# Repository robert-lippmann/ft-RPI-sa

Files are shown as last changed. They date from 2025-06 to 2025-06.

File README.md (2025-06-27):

# ft-RPI-sa
The ft-RPI-sa controller is a versatile enhancement, developed to control models primarily built with fischertechnik but can be also used with Lego or any other kind of technical toy, limited to 12V supply and I/O voltage.
It consists of the main compute board (aka mainboard), covering all the required logic circuitry, and an additional I/O board with all the inputs and outputs to connect to the model. The I/O board features standard mini-banana-plug connectors with a diameter of 2.5mm. The mainboard can  optionally be used as a Raspberry Pi HAT and is supplied by either a battery set or an external 9V power supply.

# Mainboard V2.1 Top View
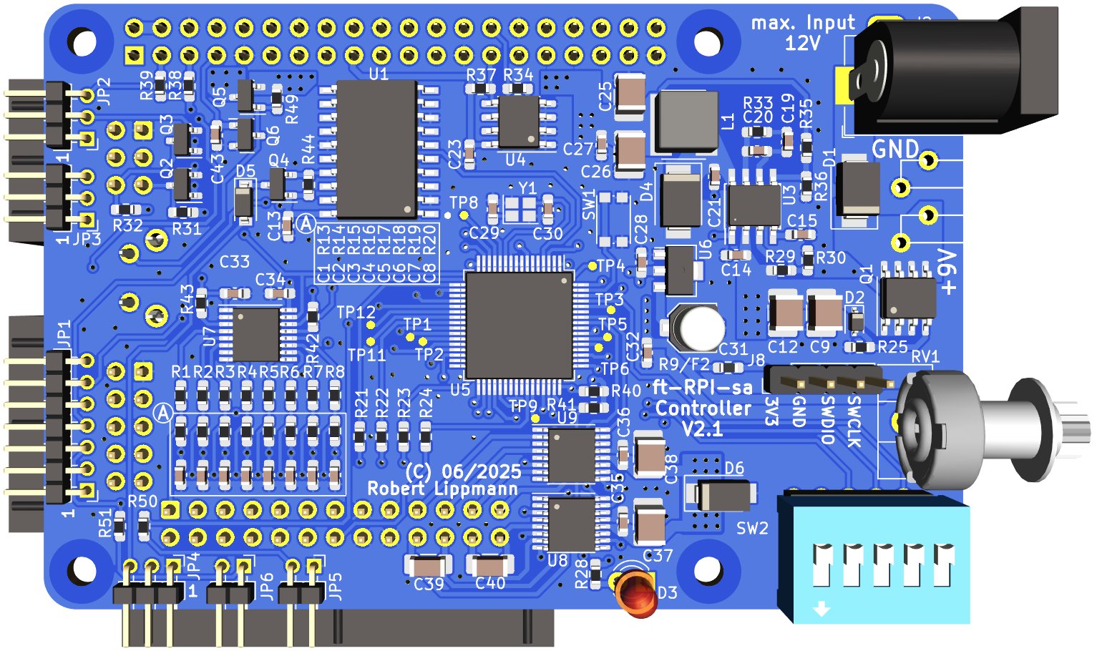
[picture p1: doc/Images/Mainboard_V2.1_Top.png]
Mainboard V2.1 Top view


# Mainboard V2.1 Bottom View
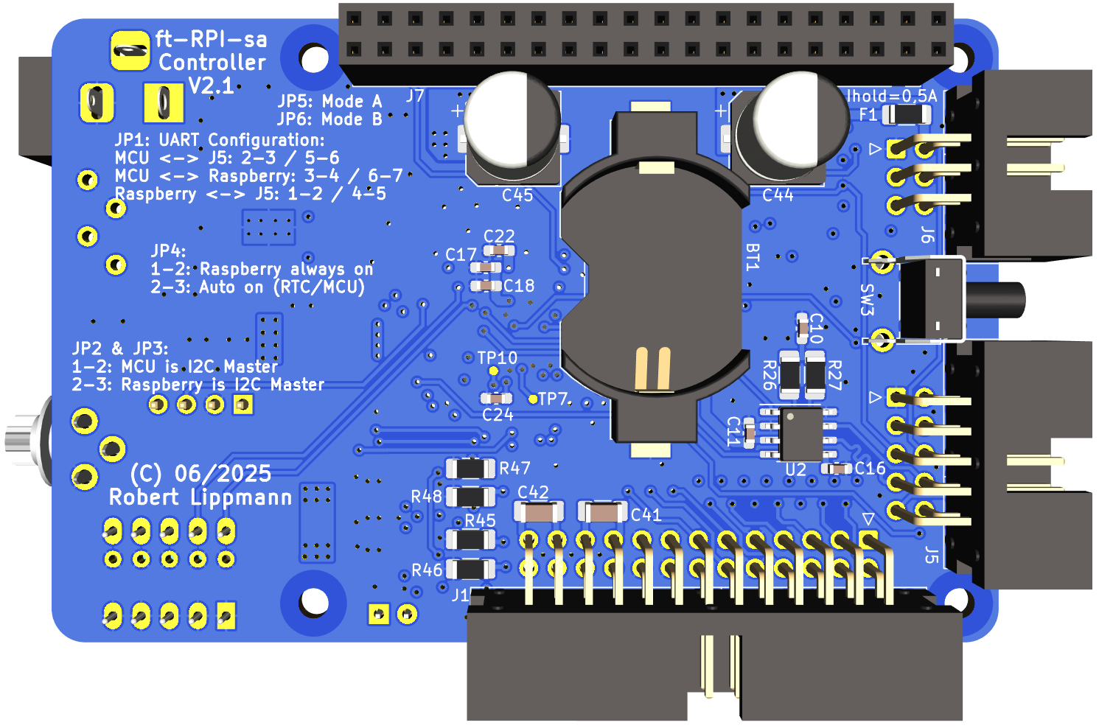
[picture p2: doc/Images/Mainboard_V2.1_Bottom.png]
Mainboard V2.1 Bottom view


# I/O Board Top View
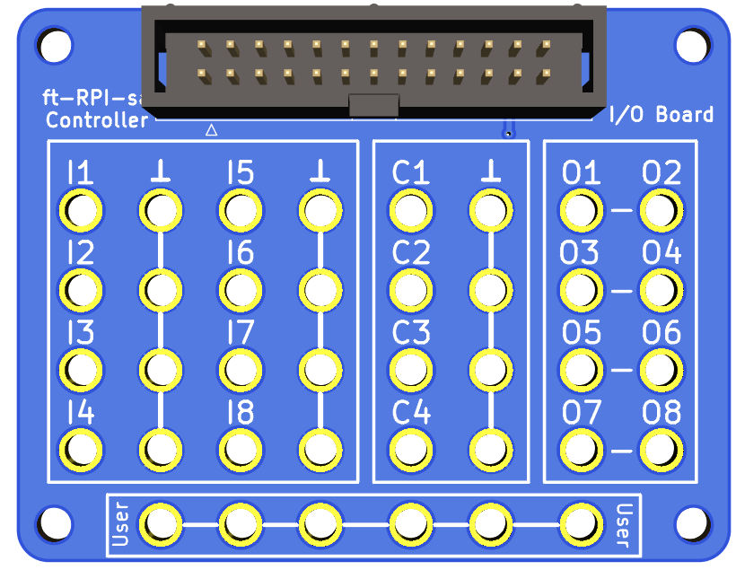
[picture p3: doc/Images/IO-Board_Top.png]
I/O Board Top view


# Features
 - Using NXP Microcontroller S32K142 or S32K144(W) or S32K146 w/o hardware modification
 - 8 independent 9V inputs (supporting analog & digital input capability with individual
   programable pull configuration)
 - 8 outputs which can be used independently or in combination for brushed or stepper Microcontroller
 - 4 independent 9V counter inputs which can use DMA for counting
 - Using a separate board for I/O connectors
 - Can be used as Raspberry Pi HAT with integrated power supply for the Raspberry Pi
 - Interfaces like UART (TTL), I2C (5V and 3V3), CAN-PHY, SPI (also useable with Raspberry Pi SPI1)
   to be used with additional peripherals
 - RTC incl. 512 Bytes RAM, w/ battery backup, useable for optional timed wakeup/activities
 - Full featured MMBasic interpreter including an editor running on S32K14x using UART
 - MMBasic interpreter enhanced with commands and functions to support on-board peripherals
 - Using a simple terminal program, running either on Raspberry Pi or on a PC/MAC, for SW development
 - Program transfer done via XMODEM up-/download to/from host computer
 - MMBasic program stored in D-Flash memory (64k) of MCU
 - Optional auto start of MMBasic application once powering up
 
# YouTube video
&nbsp;&nbsp;&nbsp;&nbsp;YouTube logo
 - [Video of 2 fischertechnik models controlled by the ft-RPI-sa](https://www.youtube.com/watch?v=sPbV3bQHXdk)

# Copyright and Acknowledgements

MMBasic interpreter:

Thanks to Geoff for granting me the permission to adapt his beautiful MMBasic interpreter to this hardware project and go public with it.
 - https://geoffg.net/micromite.html
 - Copyright 2011-2024 Geoff Graham
 - Copyright 2016-2024 Peter Mather

MMBasic enhancements and modifications related to ft-RPI-sa hardware:
- Copyright 2022-2025 Robert Lippmann
  
ft-RPI-sa Hardware:

- Copyright 2022-2025 Robert Lippmann

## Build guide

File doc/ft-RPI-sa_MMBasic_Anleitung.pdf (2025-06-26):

# ft-RPI-sa Controller

# (fischertechnik-Raspberry PI-stand-alone Controller) Anleitung HW Version 2.x MMBasic Version 5.05.05

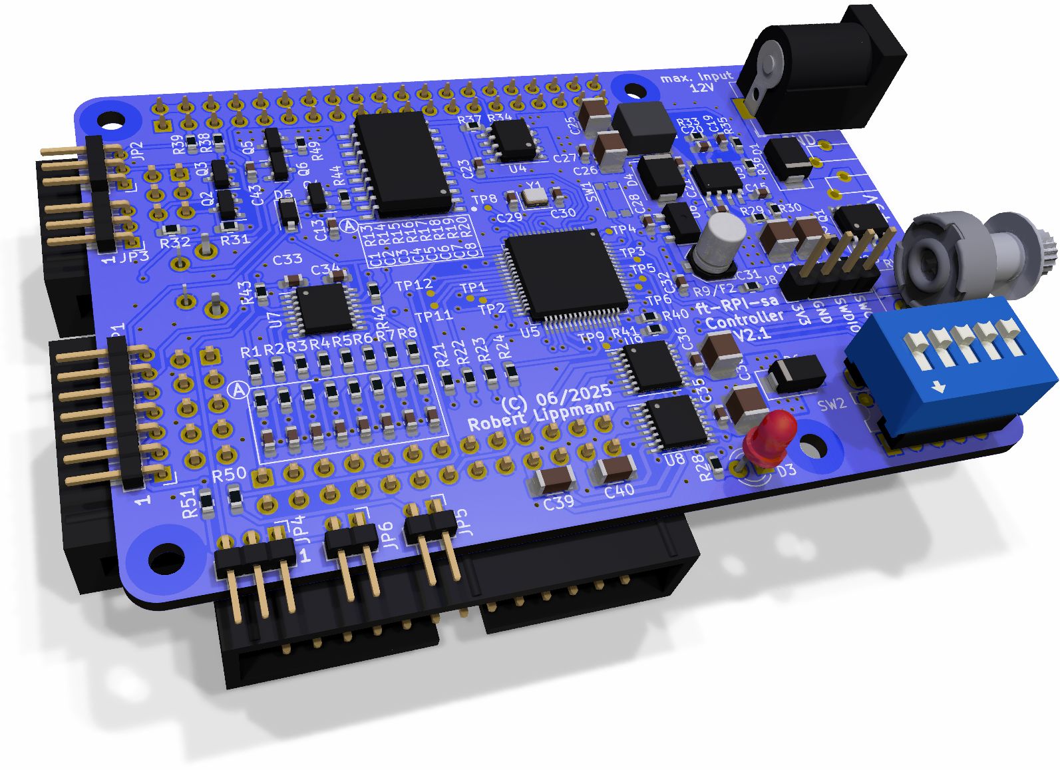
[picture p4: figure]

## MMBasic © Geoff Graham Hardware & S32K14x Adaptierung © Robert Lippmann Dokument V0.2 vom 21. Juni 2025 Projektkontakt: ft.mcu.prj@gmail.com

ft-RPI-sa Controller | Seite 1
Anleitung Version V0.2 | Entwurf

# Einleitung

Der ft-RPI-sa Controller ist ein kleiner Computer mit dem fischertechnik, Lego oder andere Technikmodelle, die mit 9V versorgt werden, gesteuert werden.
Der Controller besteht aus der Hauptplatine (auch Mainboard genannt), die all die benötigten Bausteine für die Steuerung beinhaltet, sowie einer zusätzlichem Ein-/Ausgabe Platine (I/O-Board) mit allen Anschlüssen für das zu steuernde Modell.
Die Hauptplatine, die optional auch als Raspberry Pi HAT verwendet werden kann, wird entweder durch ein passendes Batterie-Set oder Netzteil mit Spannung versorgt.

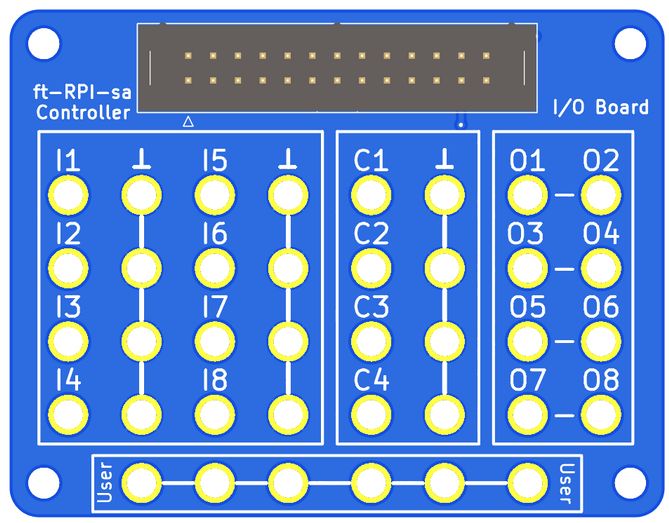
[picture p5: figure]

Das I/O Board

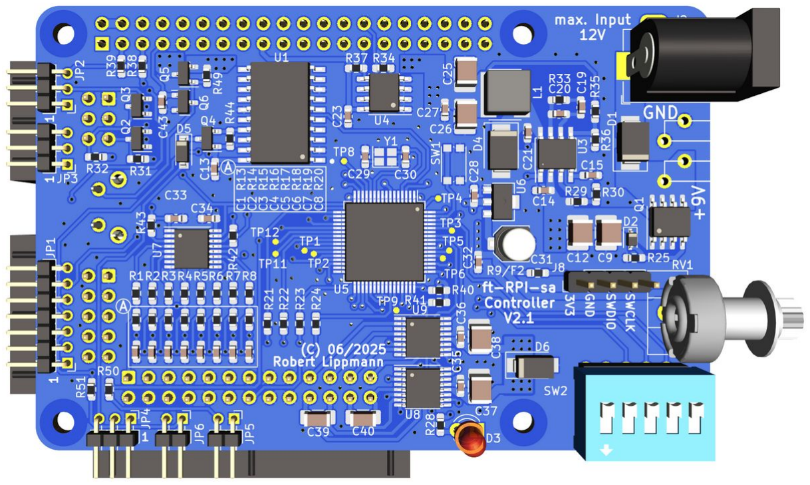
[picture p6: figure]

Das Mainboard

Das Mainboard beinhaltet einen Mikrocontroller (MCU), eine Echtzeituhr (RTC) mit Backup Batterie, Spannungsreglern, Ausgangstreibern (H-Brücken) und viele Anschlüsse sowie Konfigurationsbrücken.
Die benutzte MCU ist ein S32K144 Mikrocontroller der Firma NXP, die einen 32bit ARM CPU Kern des Typs M4F beinhaltet, welcher mit 80MHz betrieben wird. Neben der CPU besitzt die MCU viele weitere Peripheriemodule wie Flash Speicher (Programmspeicher), RAM Speicher (Arbeitsspeicher), UART, I2C, SPI, CAN, ADC, Timer etc.
Statt einer S32K144 MCU ist es auch möglich, einen anderen Typ der S32K1 Familie, im 64pin LQFP Gehäuse, zu verwenden (z.B. S32K118, S32K142(W) oder S32K146). Die Unterschiede der einzelnen MCUs, die die Leistung oder Fähigkeiten, des ft-RPI-sa Controllers beeinflussen, sind nachfolgend dargestellt:
MCU Typ | Flash Speicher | RAM Speicher | Max. CPU Geschwindigkeit | CPU Kern
S32K118¹ | 256kB | 25kB | 48MHz | Cortex M0+
S32K142(W) | | 32kB | 112MHz(80MHz) | Cortex M4
| 512kB | 64kB | incl. FPU S32K144(W)
S32K146 | 1024kB | 128kB | 112MHz
MCU Unterschiede

Wenn Du einen detaillierteren Überblick der K1 Familie haben willst, besuche die NXP Webseite. (https://www.nxp.com/products/processors-and-microcontrollers/s32-automotive-platform/s32k-auto-general-purpose-mcus/s32k1-microcontrollers-for-automotive-gene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) Dort gibt es auch das "Reference Manual", das jedes einzelne Bit der MCU erklärt.

1 Die MCU S32K118 hat keine FPU und somit sind die Fließkommaoperation deutlich langsamer, da diese in Software abgearbeitet werden müssen, und somit verweise ich auf diese MCU nur, da sie auf der Hardware eingesetzt werden kann, aber für MMBasic eignet sie sich nur bedingt.

ft-RPI-sa Controller | Seite 2

Das Mainboard kann entweder alleine, also Stand-Alone (sa), betrieben werden, oder es wird als sogenanntes HAT auf einen Raspberry Pi (RPI) gesteckt. Daher kommt auch die Bezeichnung RPI-sa Controller. Das ft am Anfang steht für fischertechnik, da ich den Controller hauptsächlich dafür entwickelt und getestet habe.

Programmiert wird der ft-RPI-sa mittels der Programmiersprache BASIC, welche schon sehr früh (ab 1964) in der Geschichte des Programmierens zu finden ist. BASIC ist sehr leicht zu erlernen und Erfolge beim Programmieren stellen sich sehr schnell ein. Das hier verwendete, so genannte MMBasic (Micromite BASIC), besitzt eine weitgehende Kompatibilität zu Microsofts GW-Basic. Dieses wurde nicht von mir, sondern von Geoff Graham entwickelt. Die Anpassung des BASIC Interpreters von Microchips PIC Familie an die NXP S32K1 Familie, sowie die Erweiterung um spezielle Instruktionen für den ft-RPI-sa, wurde von mir vorgenommen.

Wie kommt nun das BASIC Programm in den Controller? Dazu wird entweder ein Computer oder ein Raspberry PI benötigt. Sämtliche Kommunikation zwischen Controller und Computer geschieht über eine serielle Schnittstelle. Dafür sind 2 Leitungen, eine für das Senden und eine für das Empfangen der Daten, nötig. Die einfachste Art heutzutage diese beiden Leitungen mit einem PC zu verbinden, ist ein so genannter USB zu UART bzw. TTL Konverter. Dieser stellt auf dem Computer eine serielle Komponente, wie z.B. COM1 oder /dev/ttyUSB0 je nach verwendetem Betriebssystem, zur Verfügung, auf welche mit einem simplen Terminalprogramm, wie Putty, TeraTerm unter Windows oder minicom unter Linux, zugegriffen werden kann.

Eine andere, viel bequemere Möglichkeit um eine Verbindung herzustellen, ist die Verwendung eines Raspberry Pis. Dazu wird der ft-RPI-sa einfach auf den RPI gesteckt (HAT) und nach einer korrekten Konfiguration der Schnittstelle steht auch schon die Verbindung. Kein zusätzliches Kabel oder Konverter ist dazu nötig.

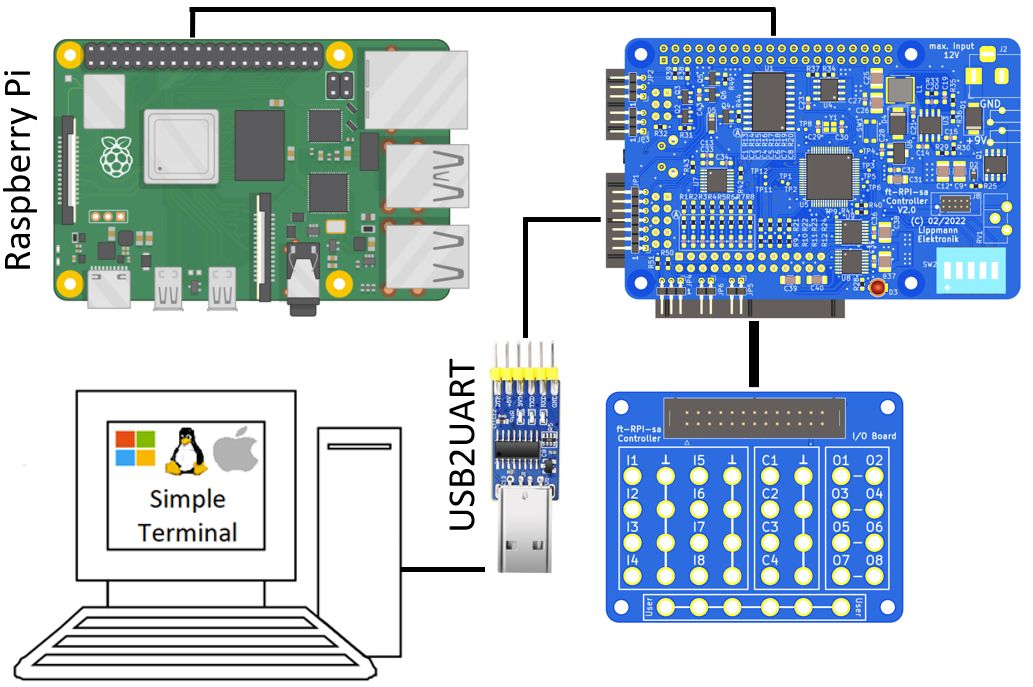
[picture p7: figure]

Verbindung über Computer oder Raspberry Pi

ft-RPI-sa Controller | Seite 3

# Die Hardware im Detail

Auf der Rückseite des Mainboards sind schon viele Konfigurationen festgehalten, aber längst nicht alle. Die folgenden Bilder sollen helfen, die Anschlüsse und deren Benutzung zu erklären:

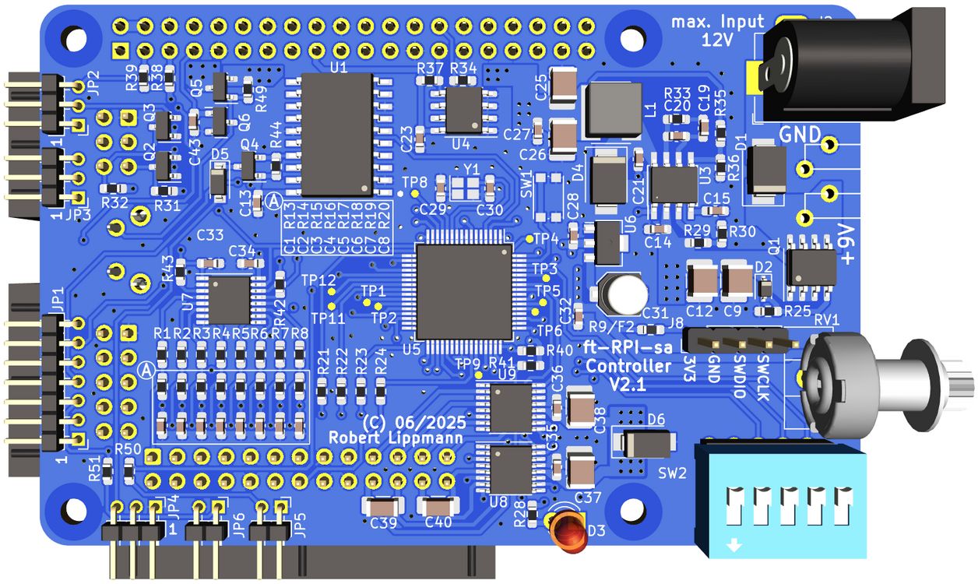
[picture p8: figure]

Ansicht Mainboard von oben

Beide Anschlüsse für die Stromversorgung sind gegen Verpolung geschützt!

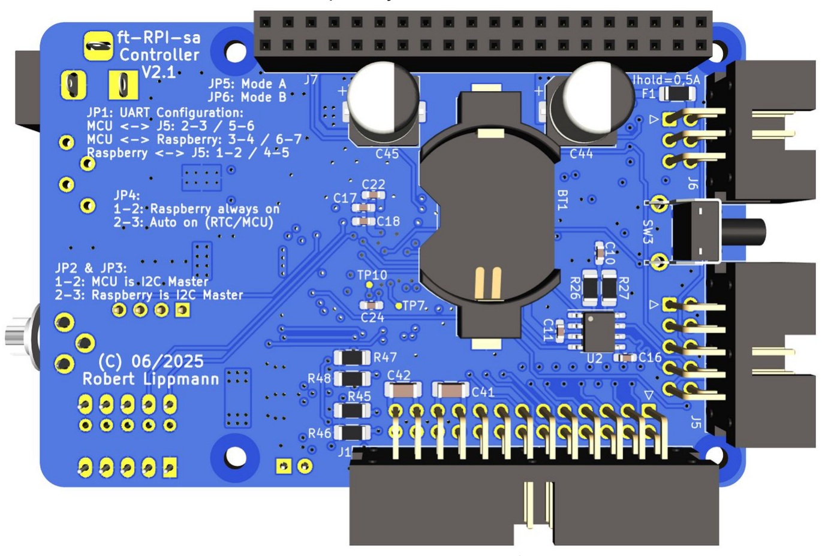
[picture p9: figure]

Ansicht Mainboard von unten

ft-RPI-sa Controller | Seite 4

J6:
I2C Schnittstelle (5V)
5V Stromversorgung für ext. Peripherie (max 0.5A /abgesichert) SW3:
Raspberry Pi Einschaltknopf

J5:
I2C Schnittstelle (3V3)
CAN Schnittstelle (5V)
UART (serielle Schnittstelle)

J7: Raspberry Pi Anschluss / SPI Schnittstelle

J2: Eingang
Stromversorgung (12V max)
GND (2.5mm Anschluss)
+9V (2.5mm Anschluss)

SW1: MCU RESET

J8: ARM Debugger Anschluss

Potentiometer

SW2: DIP Schalter

JP4: Raspberry Pi Versorgung Config D3: Versorgung/Status LED JP5/JP6: Für spezielle Modi

JP2/JP3: I2C Config

JP1: UART Config

J1: Anschluss für das I/O-Board

# Konfiguration

JP1
JP1: UART Konfiguration

Eine Verbindung zwischen:
2-3 & 5-6 : MCU ↔ J5 (Externer Computer mit Terminalprogramm) 3-4 & 6-7 : MCU ↔ Raspberry Pi (mit Terminalprogramm)
1-2 & 4-5 : Raspberry Pi ↔ J5

JP2 / JP3: I2C Konfiguration

1-2: MCU ist I2C Master (Standard für MMBasic Betrieb) | JP2
2-3: Raspberry Pi ist I2C Master

JP3

JP4 JP6 JP5
JP4: Raspberry Pi Versorgung
1-2: Raspberry PI ist immer an
2-3: Raspberry PI ist aus, kann aber über den Taster (SW3), die MCU oder einen RTC Alarm eingeschaltet werden
OFF: Raspberry Pi ist immer aus

JP5 / JP6:
Werden benötigt um den Bootloader zu aktivieren und eine neue Firmware einzuspielen.

J5 & J6: Anschlüsse für Peripherie

J6 | J5
5V I2C Anschluss | I2C/UART/CAN Anschluss
ft-RPI-sa Controller | Seite 5
SCL | SDA
NC | NC
+5V | GND
UART RX | UART TX
CANH | CANL
SCL | SDA
NC | NC
NC | GND

UART und I2C verwenden 3.3V CAN verwendet 5V

Die +5V können für externe Peripherie verwendet werden und sind mit 500mA abgesichert.

J7: Raspberry PI GPIO Anschluss
Dieser Anschluss ermöglicht ein aufstecken des Controllers auf den Raspberry PI (HAT = Hardware Attached to the Top).

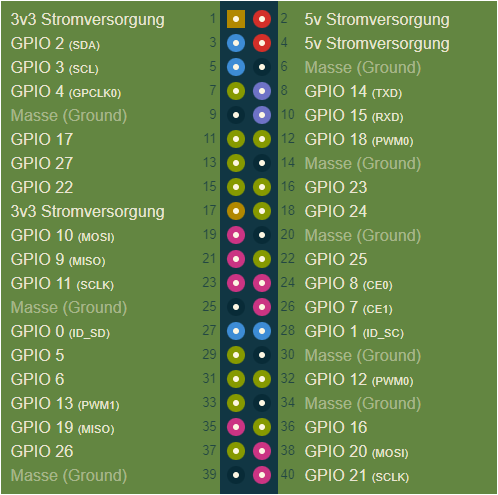
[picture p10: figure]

Raspberry Pi Belegung (https://de.pinout.xyz/)

Durch das Aufstecken des Controllers auf einen RPI wird die MCU interne LPSPI0 an die SPI1 des Raspberry Pis angeschlossen. Diese Art der synchronen, seriellen Schnittstelle ist verhältnismäßig schnell (bis zu 10MHz) und lässt sich relativ einfach verwenden.

SPI1 des RPIs an die LPSPI0 der MCU

Falls die Kommunikation, über die SPI1 des Raspberry Pis, zu dem ft-RPI-sa nicht verwendet wird, oder generell auf einen Raspberry Pi verzichtet wird, kann die MCU interne LPSPI0 für jede andere Art von Peripherie genutzt werden.

Weitere HATs können problemlos auf den ft-RPI-sa Controller gesteckt werden. Dazu musst Du nur darauf achten, dass GPIO4 nicht verwendet werden kann. Dieser wird dazu verwendet, dem ft-RPI-sa mitzuteilen, dass der Raspberry PI eingeschaltet ist und diesem die Versorgung nicht abschaltet ist.

Wie gerade erwähnt, wird der Raspberry Pi vom ft-RPI-sa Controller versorgt und stellt diesem auch einen Einschaltknopf bereit.
Abhängig von J4 kann der Raspberry PI sich aber auch automatisch einschalten, entweder per MCU oder per Alarm, gesteuert von der Echtzeituhr auf dem ft-RPI-sa.
Der Raspberry PI 4 verbraucht im Betrieb bei 5V ca. 600mA, kann aber auch bis zu 1.5A ansteigen, je nach Auslastung des Systems. Da ein sogenannter Schaltregler verwendet wird, um den Raspberry PI zu versorgen, beträgt der Strom auf der 9V Seite, je nach Auslastung, nur ca. 300mA bzw. ca. 800mA.
ft-RPI-sa Controller | Seite 6

Derzeit besteht die einzige Aufgabe des Raspberry PIs darin, den Standard PC als I/O Terminal zu ersetzten - weitere Einsatzmöglichkeiten sind aber schon geplant.

J1: I/O-Board Anschlüsse
Auf dieser Platine sind 2.5mm Buchsen untergebracht, von denen aus der Controller mit den einzelnen Sensoren und Aktoren der Modelle verbunden wird.

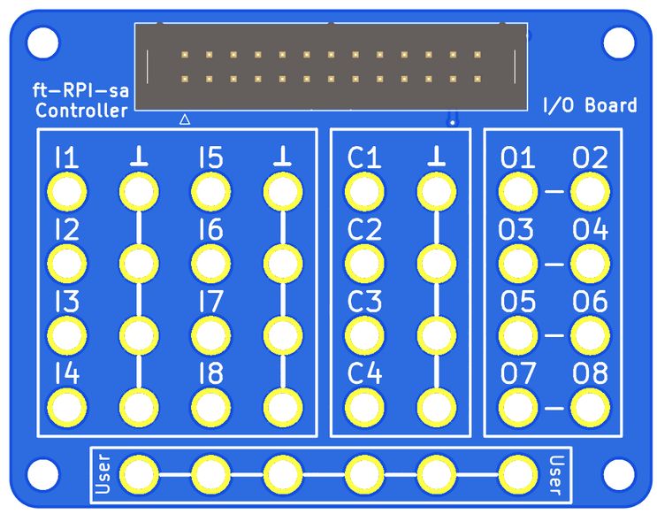
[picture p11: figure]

I/O Board

Alle GND (Masse) Verbindungen sind mit einem “Ʇ Symbol gekennzeichnet und miteinander verbunden.
Zusätzlich gibt es 8 Eingänge die mit I1 bis I8, sowie 4 Zählereingänge die mit C1 bis C4 gekennzeichnet sind. Neben all den Eingängen gibt es 8 Ausgänge O1 bis O8.
An der unteren Kante ist eine Reihe mit Buchsen versehen, die alle miteinander verbunden sind und die Kennzeichnung "User" haben. Diese 6 Buchsen können als Verteiler verwendet werden.

Die Ausgänge können verschiedenste Aktoren, wie (Schritt-)Motoren, Ventile, Elektromagnete, Lampen etc., mit maximal ~700mA steuern. Jeder der Ausgänge ist individuell steuerbar, für Motoren können jedoch 2 Ausgänge miteinander verbunden werden, um eine vollständige Kontrolle des Motors (Rechtslauf, Linkslauf, Schnelle Bremse oder Ausgleiten) zu bekommen. Dafür sind die zusammengehörigen Ausgänge mit einem Strich dazwischen, auf dem I/O Board gekennzeichnet.
Es kann auch ein Schrittmotor angeschlossen werden. Dazu sind jedoch 4 Ausgänge nötig. In diesem Fall werden die Ausgänge 1 bis 4, sowie 5 bis 8 gruppiert.

Die Eingänge I1 bis I8 sind alle identisch aufgebaut. Jeder der Eingänge verfügt über einen konfigurierbaren 2.7kΩ Pull Widerstand, der wahlweise nach +5V, nach GND oder ganz abgeschaltet werden kann. Mit diesem Pull Widerstand kann ein Eingang, auch wenn er nicht beschaltet ist, auf einen definierten Wert gebracht werden.

Die Zählereingänge C1 bis C4 besitzen keine Pull Möglichkeit und werden von der MCU auf zwei verschiedene Arten realisiert. Zum Einen wird jeder der Zählereingänge jede Millisekunde abgefragt und sobald eine stabile Zustandsänderung von 9V auf 0V stattgefunden hat, der Zähler um 1 weiter gezählt. Somit lassen sich Zustandsänderungen bis maximal 125 mal in der Sekunde erfassen, da für die stabile Zustandsänderung 2x 4 Durchläufe bzw. 8ms benötigt werden. Diese Methode ist dafür geeignet, mechanische Schalter abzufragen, da diese bei der Betätigung mehrere Impulse liefern - das sogenannte Prellen.
Zum Anderen verfügt die MCU über die Möglichkeit, eine Zustandsänderung automatisch zu erfassen ohne Zutun der CPU. Dies erlaubt es, mehr als 100000 Zustandsänderungen pro Sekunde zu verarbeiten. Diese Version der Zähler ist für jede prell-freie Quelle (z.B. Encoder-Motor) zu verwenden.
ft-RPI-sa Controller | Seite 7

# Der MMBasic Interpreter

Wie bereits erwähnt, ist MMBasic an das von Microsoft entwickelte GW-Basic angelehnt, jedoch verwendet es keine Zeilennummern. Dies ist ein wesentlicher Vorteil, da es somit nicht so leicht zu dem, bei BASIC Programmen besonders gefürchteten, Spaghetti-Code kommen kann.

# Das Terminal (oder: Die Konsole)

Um den ft-RPI-sa in MMBasic zu programmieren, benutzt man ein Terminal. Ein Terminal ist ein Programm auf dem PC, dass über eine serielle Schnittstelle eine Verbindung zum ft-RPI-sa Controller herstellt. Darüber kann man Kommandos eingeben, um den Controller zu konfigurieren oder zu programmieren, um ein BASIC Programm zu laden oder auch nur das BASIC Programm zu starten.
Das Terminal ist die einzige Möglichkeit um mit dem ft-RPI-sa Controller zu kommunizieren. Es ist daher essentiell diese Verbindung herzustellen. Eine serielle Verbindung besteht aus zwei Leitungen. Eine, oft bezeichnet als Tx, wird zum Senden der Daten und eine weitere Leitung, bezeichet als Rx, wird zum Empfangen der Daten verwendet. Die Nutzdaten, im ASCII Format, werden umrahmt von einem Start- und einem Stopbit:

Die Geschwindigkeit der Übertragung wird in Baud angegeben, was Bits pro Sekunde entspricht. Der ft-RPI-sa Controller verwendet, sobald er eingeschaltet wird, eine Geschwindigkeit von 19200 Baud. Diese kann jedoch, an das verwendete System, angepasst werden. Dazu später mehr. Der Signalpegel auf den Rx/Tx Leitungen schwankt, je nach zu
übertragendem Bit-Wert, zwischen 0V und 3.3V, auch TTL Pegel
genannt. Um diese beiden Leitungen nun an den PC anzuschließen,
ist ein Adapter von USB nach TTL nötig. Dieser ist bereits für kleines Geld im Internet erhältlich.
Dieser USB nach TTL Konverter stellt, sobald dieser am USB Port

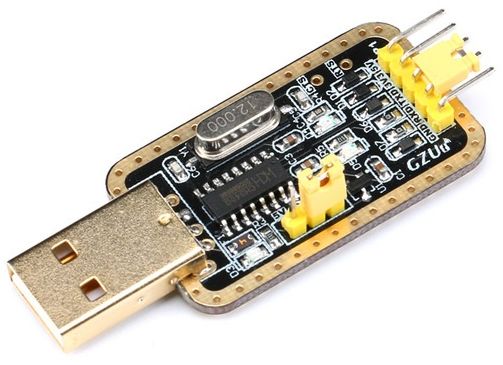
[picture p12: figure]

des Computer eingesteckt wird, ein serielles Interface zur Verfügung.
Je nach verwendetem Betriebssystem ist dies entweder "COMx"
(Windows) oder "/dev/ttyUSBx" (Linux). Das x entspricht einer Zahl
beginnend bei 1 (Win) oder 0 (Linux) und kann je nach Anzahl der verwendeten Adapter variieren. Auf diese Schnittstellen lässt sich nun mit Hilfe eines entsprechendem Terminalprogramms zugreifen. Unter Windows wäre dies z.B. Putty, TeraTerm und unter Linux kann z.B. minicom verwendet werden.
Um den ft-RPI-sa Controller nun mit dem PC zu verbinden, werden die entsprechenden Signale an dem Anschluss J5 abgegriffen und mit den Anschlüssen des Konverters verbunden:
J5/UART_RX -> USB2TTL TX sowie
J5/UART_TX -> USB2TTL RX
Jetzt kann jemand fragen, wieso nicht RX auf RX bzw. TX auf TX. Ganz einfach: Einen Sender (TX) muss man an einen Empfänger (RX) anschließen.
Eine weitere, bis jetzt noch nicht erwähnte Leitung, muss ebenfalls angeschlossen werden: GND Dies ist der gemeinsame Bezugspunkt zwischen Computer und ft-RPI-sa Controller.
Sobald alle drei Leitungen verdrahtet sind, kann die erste Kontaktaufnahme gestartet werden und im richtig konfiguriertem Terminalprogramm sollte nach dem Einschalten des ft-RPI-sa Controllers ungefähr folgendes zu sehen sein:
ft-RPI-sa Controller | Seite 8

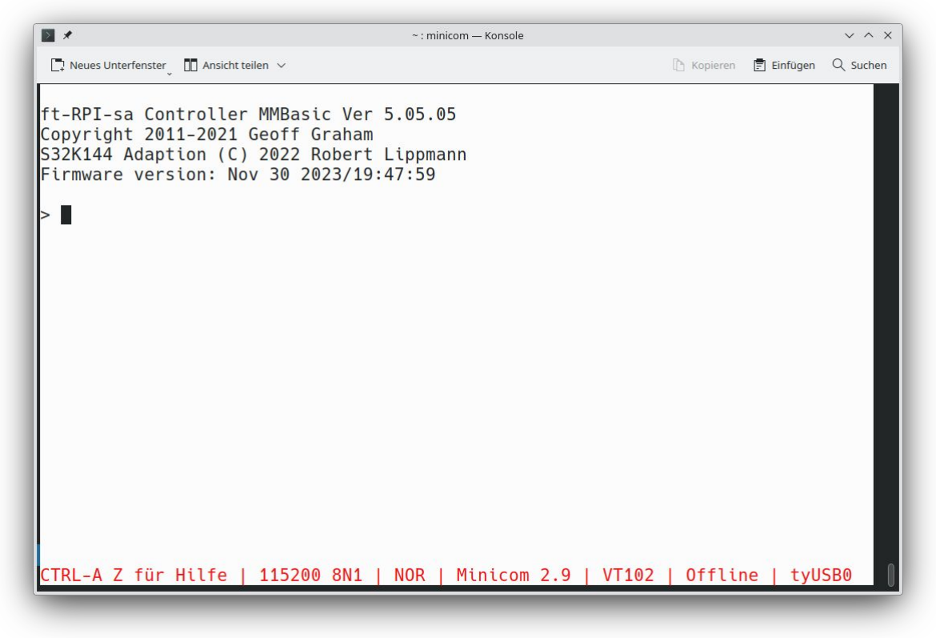
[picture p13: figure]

Falls dies nicht der Fall sein sollte: KEINE PANIK!
- Leuchtet die Status-/Power-LED des ft-RPI-sa?
- Sind die beiden Kurzschlussbrücken an JP1 richtig gesetzt?
- Stimmt die eingestellte Baudrate, also Übertragungsgeschwindigkeit, überein?
- Stimmen die Übertragungsparameter (8 Datenbits, 1 Stopbit und keine Parität)?
- Sind die Verbindungen von ft-RPI-sa zu USB2TTL korrekt?
- Funktioniert der USB2TTL Konverter? (Test: Kurzschlussbrücke am USB2TTL auf RX/TX setzen und tippen - jedes gesendetes Zeichen sollte im Terminalprogramm zu sehen sein)

Falls ein Raspberry Pi griffbereit ist, kann der ft-RPI-sa Controller auch auf den Raspberry Pi gesteckt werden. In diesem Fall ist kein USB2TTL Converter nötig und nach entsprechendem konfigurieren der Kurzschlussbrücken auf JP1 kann der Raspberry Pi auch schon den PC ersetzen.

Da MMBasic selbst, sowie dessen Befehls- und Funktionsumfang, vom Autor Geoff Graham bereits ordentlich dokumentiert wurde, folgt hier nun eine Kopie seines erstellten Dokuments mit Anpassungen bezüglich ft-RPI-sa spezifischen Befehlen und Funktionen:

ft-RPI-sa Controller | Seite 9

# Interacting with MMBasic

The ft-RPI-sa is rather like a self contained computer. You can write programs, run them, edit them and so on, all on the ft-RPI-sa itself. And if your program has an error (as initially
all do) you will get a clear message showing you where the fault is located and what the
problem is. This is different from other systems where you build your program on a
separate computer then download the compiled result to the chip to be run. In that case you do not get any feedback on errors while your program is running… it will just produce crazy results and you will have no idea where or what in your program caused the problem.
This is an important part of working with the ft-RPI-sa – it is much easier and quicker to build a functioning program when you can get immediate feedback and then, with one keystroke, jump into an editor to fix the issue and run the program again.
This interaction with the ft-RPI-sa is done via the console at the command prompt (ie, the greater than symbol (>) on the console). On startup the ft-RPI-sa will issue the command prompt and wait for some command to be entered. It will also return to the command prompt if your program ends or if it generated an error message.
When the command prompt is displayed you have a wide range of commands that you can execute.
Typically your commands would list the program held in flash memory (LIST) or edit it (EDIT) or perhaps set some options (the OPTION command). Most times the command is just RUN which instructs MMBasic to run the program held in flash memory.
Almost any command can be entered at the command prompt and this is often used to test a command to see how it works. A simple example is the PRINT command (more on this in Chapter 3), which you can test by entering the following at the command prompt:

PRINT 2 + 2
and not surprisingly MMBasic will print out the number 4 before returning to the command prompt. This ability to test a command at the command prompt is very useful when you are learning to program in BASIC, so it would be worthwhile having a ft-RPI-sa handy for the occasional test while you are working through this tutorial.

# Break Key

One useful feature of the ft-RPI-sa is the CTRL-C sequence (hold down the CTRL key then press the C key). This is called the break key or character. When you type this on the console’s input it will interrupt whatever the ft-RPI-sa is doing and immediately return control to the command prompt.
This can get you out of all sorts of difficult situations. For example, if you entered the following at the command prompt you would cause MMBasic to enter a continuous loop and appear to be unresponsive.
DO : LOOP
If you have a ft-RPI-sa handy you can try entering this line and you will see that the command prompt does not return because MMBasic is busy spinning in a loop. Then try typing CTRL-C on the console and the ft-RPI-sa will immediately break out of the loop and return to the command prompt.
Remember CTRL-C because it will prove useful at some time in the future.
ft-RPI-sa Controller | Seite 10

The Editor
The ft-RPI-sa has its own built in program editor which can be used to enter programs and correct them when errors are discovered. This screen shot shows the editor in action with colour coded text. Commands are in cyan, comments in yellow, constants in green and so on as shown below.

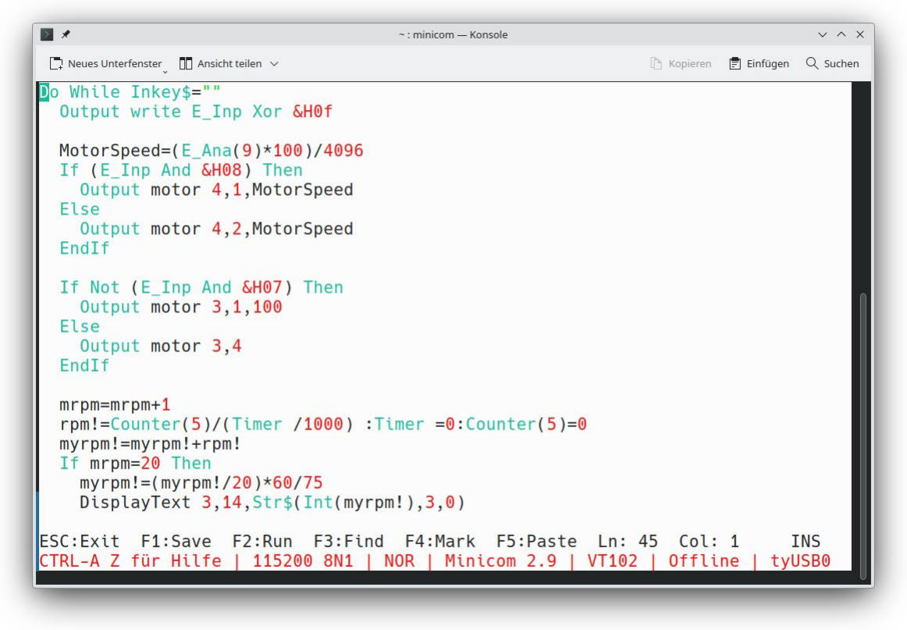
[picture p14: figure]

The best way to understand the editor is to try it out. At the command prompt enter the command EDIT and the editor will startup displaying an empty screen with a help line at the bottom of the screen. You can then just type in your program. For example, try typing in:
PRINT 1/7
Then press the F2 key on your keyboard. This will save the program to memory and run it. This will display the result of dividing 1 by 7.
To change this program use the command EDIT again and you will be taken back into the editor with your program displayed ready for editing.
If you have used an editor like Windows Notepad in the past you will find the operation of this editor familiar. The arrow keys will move your cursor around in the text while the home and end keys will take you to the beginning or end of the line. Page up and page down will do what their titles suggest. The delete key will delete the character at the cursor and backspace will delete the character before the cursor.

About the only unusual key combination is that two home key presses will take you to the start of the program and two end key presses will take you to the end. At the bottom of the screen the status
line will list the various function keys used by the editor and their action. In more details these are:
ft-RPI-sa Controller | Seite 11

ESC | This will cause the editor to abandon all changes and return to the command prompt with the program memory unchanged. If you have changed the text you will be asked if you really want to discard your changes.
F1: SAVE | This will save the program to program memory and return to the command prompt.
F2: RUN | This will save the program to program memory and immediately run it.
F3: FIND | This will prompt for the text that you want to search for. When you press enter the cursor will be placed at the start of the first entry found.
SHIFT-F3 | After you have used the search function once you can repeatedly search for the same text by pressing SHIFT-F3.
F4: MARK | This is described in detail below.
F5: PASTE | This will insert (at the current cursor position) the text that had been previously cut or copied to the ft-RPI-sa clipboard (see below).

If you pressed the mark key (F4) the editor will change to the mark mode. In this mode you can use the arrow keys to mark a section of text which will be highlighted in reverse video. You can then delete, cut or copy the marked text to the ft-RPI-sa's clipboard. In this mode the status line will change to show the functions of the function keys in the mark mode. These keys are:

ESC
F4: CUT
F5: COPY
DELETE

Will exit mark mode without changing anything.
Will copy the marked text to the clipboard and remove it from the text. Will just copy the marked text to the clipboard.
Will delete the text leaving the clipboard unchanged.
One point to note is that you cannot use the Windows/Linux Copy and Paste function to paste text into the terminal emulator and expect the editor to accept it. This is because the editor has a lot of work to do for each character received and it cannot keep up with a high speed transfer like that. If you do want to copy and paste a program into the terminal emulator you should use the
AUTOSAVE command described below.

# Loading a Program from a PC

If you prepare a program on your desktop computer you can transfer it to the ft-RPI-sa using either the AUTOSAVE or XMODEM commands. This requires you to have a terminal emulator running on your desktop machine and connected to the console of the ft-RPI-sa. How to do this was described in the previous chapter.
The AUTOSAVE command puts the ft-RPI-sa into a mode where anything received on the console will be saved to the program memory. This means that you can simply copy the text and paste it into the terminal emulator (eg, minicom) which will send it to the ft-RPI-sa. From the ft-RPI-sa’s perspective pasting text into the terminal emulator is the same as if a high speed typist was typing in the program. To terminate the AUTOSAVE command you need to press the Control-Z keys in the terminal emulator and the ft-RPI-sa will save the program to its memory and return to the command prompt.
You can try this if you have a ft-RPI-sa in front of you. At the console type AUTOSAVE and
press Enter. You will see nothing on the screen because the ft-RPI-sa is waiting for the input.
Copy the program to your computer's clipboard and paste it into your terminal emulator. You should see the program text being echoed back. Enter CTRL-Z and MMBasic will confirm that it has saved the program. Then it is just a case of entering RUN at the command prompt.
The XMODEM command is more sophisticated, it uses the XModem protocol to transfer a BASIC
ft-RPI-sa Controller | Seite 12

program file from your personal computer to the ft-RPI-sa including an integrity check which will detect any errors in the transfer. This program file will be saved in the ft-RPI-sa’s memory ready to be run.
To start the XModem transfer you need to tell the ft-RPI-sa to receive the file. The command to do this is:

XMODEM RECEIVE

This instructs the ft-RPI-sa to look for an XModem connection on the console. After running this command you should then instruct your terminal program to send the file using the XModem protocol. In minicom (running on your PC) this is done by using the following menu selection: CTRL-A → Z → S → XMODEM
This will present a dialog box where you can enter/select the name of the file to be sent and when you click on OK the transfer will start. When the complete file has been received the ft-RPI-sa will save it in program memory and return to the command prompt.

# Setting Options

There are many options that you can set in the ft-RPI-sa and these are all set using the OPTION command. These settings are divided into some that will only last for the duration of the currently running program and therefore are used in a program and others that will be remembered even after
the power has been removed. These are most often entered at the command prompt.
When the ft-RPI-sa is first used the options will have been set to reasonable defaults, so you should not need to change them. But, to give you the flavor of what you can do, the following is a summary of the important settings that are available.
OPTION AUTORUN OFF | ON
OPTION BASE [0 | 1]
OPTION BAUDRATE nbr
OPTION BREAK nn
OPTION CASE [UPPER | LOWER | TITLE]
OPTION COLOURCODE ON | OFF
OPTION DEFAULT [FLOAT | INTEGER | STRING |
NONE]
OPTION DISPLAY lines [,chars]
OPTION EXPLICIT

OPTION RESET
OPTION TAB [2 | 4 | 8]

Run the program when power is applied Set the lower limit of arrays
Change the baudrate of the console
Set the character that will break out of a program
Set the format for listing commands Enable colour coding in the program editor
Set the default type of a variable

Size of the display for listing programs Require that variables be properly declared
Reset all options to their defaults
Set the size of tabs
ft-RPI-sa Controller | Seite 13

# Programming Fundamentals

The ft-RPI-sa is programmed using the BASIC programming language. The ft-RPI-sa
version of BASIC is called MMBasic (short for the origin MicroMite BASIC) which is loosely based on the Microsoft BASIC interpreter that was popular years ago.
The BASIC language was introduced in 1964 by Dartmouth College in the USA as a computer language for teaching programming and accordingly it is easy to use and learn. At the same time, it has proved to be a competent and powerful programming language and as a result it became very popular in the 70s and 80s. Even today some large commercial data systems are still written in the BASIC language (primarily Pick Basic).
For the ft-RPI-sa the greatest advantage of BASIC is its ease of use. Some more modern languages such as C and C++ can be truly mind bending but with BASIC you can start with a one line program and get something sensible out of it. MMBasic is also powerful in that you can control the I/O pins on the ft-RPI-sa or communicate with other chips using a range of built-in communications protocols.
The only significant downside to using a BASIC interpreter is that it is not as fast as a fully compiled language like C or C++. However, on a fast microcontroller such as the S32K144W MMBasic will execute each command in an average of 50µs or faster. This speed is suitable for most applications - for example, it is fast enough to respond to a high revving engine and deal with signals such as ignition triggers.

# Structure of a BASIC Program

A BASIC program starts at the first line and continues until it runs off the end of the program or hits an END command - at which point MMBasic will display the command prompt (>) on the console and wait for something to be entered.
A program consists of a number of statements or commands, each of which will cause the BASIC interpreter to do something (the words statement and command generally mean the same and are used interchangeable in this book). Normally each statement is on its own line but you can have multiple statements in the one line separated by the colon character (:). For example;
A = 24.6 : PRINT A
Each line can start with a line number. Line numbers were mandatory in the early BASIC interpreters however modern implementations (such as MMBasic) do not need them. You can still use them if you wish but they have no benefit and generally just clutter up your programs. This is an example of a program that uses line numbers:

50 A = 24.6
60 PRINT A

A line can also start with a label which can be used as the target for a program jump using the GOTO command. This will be explained in more detail when we cover the GOTO command but this is an example (the label name is JmpBack):

JmpBack: A = A + 1
PRINT A
GOTO JmpBack

# The PRINT Command

There are a number of common commands that are fundamental and we will cover them in this

ft-RPI-sa Controller | Seite 14

chapter but arguably the most useful is the PRINT command. Its job is simple; to print something on the console. This is mostly used to tell you how your program is running and can consist of something simple such as "Pump running" or "Total Flow: 23 litres".
PRINT is also useful when you are tracing a fault in your program; you can use it to print out the values of variables, I/O pins and display messages at key stages in the execution of the program. In its simplest form the command will just print whatever is on its command line. So, for example:

PRINT 54

Will display on the console the number 54 followed by a new line.
The data to be printed can be an expression, which means something to be calculated. We will cover expressions in more detail later but as an example the following:

> PRINT 3/21
0.142857
>

would calculate the result of three divided by twenty one and display it. Note that the greater than symbol (>) is the command prompt produced by MMBasic – you do not type that in.
Other examples of the PRINT command include:

> PRINT "Hello World"
Hello World
> PRINT (999 + 1) / 5
200
>

You can try these out at the command prompt.
The PRINT command will also work with multiple values at the same time, for example:

> PRINT "The amount is" 345 " and the second amount is" 456
The amount is 345 and the second amount is 456
>

Normally each value is separated by a space character as shown in the previous example but you can also separate values with a comma (,). The comma will cause a tab to be inserted between the two values. In MMBasic tabs in the PRINT command are eight characters apart. To illustrate tabbing the following command prints a tabbed list of numbers:

> PRINT 12, 34, 9.4, 1000
12 34 9.4 1000
>

Note that there is a space printed before each number. This space is a place holder for the minus symbol (-) in case the value is negative. Notice the difference with the number 12 in this example:

> PRINT -12, 34, -9.4, 1000
-12 34 -9.4 1000
>

The print statement can be terminated with a semicolon (;). This will prevent the PRINT command from moving to a new line when it completes printing all the text. For example:

PRINT "This will be";

ft-RPI-sa Controller | Seite 15

PRINT " printed on a single line."

Will result in this output:

This will be printed on a single line.

The message would be look like this without the semicolon at the end of the first line:

This will be
printed on a single line.

# Variables

Before we go much further we need to define what a "variable" is as they are fundamental to the operation of the BASIC language (in fact, any programming language). A variable is simply a place to store an item of data (ie, its "value"). This value can be changed as the program runs which
why it is called a "variable".
Variables in MMBasic can be one of three types. The most common is floating point and this is automatically assumed if the type of the variable is not specified. The other two types are integer and string and we will cover them later. A floating point number is an ordinary number which can contain a decimal point. For example 3.45 or -0.023 or 100.00 are all floating point numbers.
A variable can be used to store a number and it can then be used in the same manner as the number
itself, in which case it will represent the value of the last number assigned to it.
As a simple example:

A = 3
B = 4
PRINT A + B

will display the number 7. In this case both A and B are variables and MMBasic used their current values in the PRINT statement. MMBasic will automatically create a variable when it first encounters it so the statement A = 3 both created a floating point variable (the default type) with the name of A and then it assigned the value of 3 to it.
The name of a variable must start with a letter while the remainder of the name can use letters, numbers, the underscore or the full stop (or period) characters. The name can be up to 32 characters
long and the case (ie, capitals or not) is not important. Here are some examples:

Total_Count
ForeColour
temp3
count

You can change the value of a variable anywhere in your program by using the assignment command, ie:

variable = expression

For example:

ft-RPI-sa Controller | Seite 16

temp3 = 24.6
count = 5
CTemp = (FTemp – 32) * 0.5556

In the last example both CTemp and FTemp are variables and this line converts the value of FTemp (in degrees Fahrenheit) to degrees Celsius and stores the result in the variable Ctemp.

# Expressions

We have met the term ‘expression’ before in this tutorial and in programming it has a specific meaning. It is a formula which can be resolved by the BASIC interpreter to a single number or value.
MMBasic will evaluate a mathematical expression using the same rules that we all learnt at school. For example, multiplication and division are performed first followed by addition and subtraction. These are called the rules of precedence and are fully spelt out in the manual (around page 52). This means that 2 + 3 * 6 will resolve to 20, so will 5 * 4 and also 10 + 4 * 3 – 2.
If you want to force the interpreter to evaluate parts of the expression first you can surround that part of the expression with brackets. For example, (10 + 4) * (3 – 2) will resolve to 14 not 20 as would have been the case if the brackets were not used. Using brackets does not appreciably slow down the program so you should use them liberally if there is a chance that MMBasic will misinterpret your expression.
As pointed out earlier, you can use variables in an expression exactly the same as straight numbers.
For example, this will increment the value of the variable temp by one:

temp = temp + 1

You can also use functions in expressions. These are special operations provided by MMBasic, for example to calculate trigonometric values. As an example, the following will print the length of the hypotenuse of a right angled triangle using the SQR() function which returns the square root of a number (a and b are variables holding the lengths of the other sides):

PRINT SQR(a * a + b * b)

MMBasic will first evaluate this expression by multiplying a by a, then multiplying b by b, then adding the results together. The resulting number is then passed to the SQR() function which will calculate the square root of that number and return it for the PRINT command to display.
Some other mathematical functions provided by MMBasic include:
SIN(r) – the sine of r
COS(r) – the cosine of r
TAN(r) – the tangent of r
There are many more functions available to you and they are all listed in the User Manual.
Note that in the above functions the value passed to the function (ie, 'r') is the angle in radians. In MMBasic you can use the function RAD(d) to convert an angle from degrees to radians ('d' is the angle in degrees).

Another feature of BASIC is that you can nest function calls within each other. For example, given the angle in degrees (ie, 'd') the sine of that angle can be found with this expression:

ft-RPI-sa Controller | Seite 17

PRINT SIN(RAD(d))

In this case MMBasic will first take the value of d and convert it to radians using the RAD() function. The output of this function then becomes the input to the SIN() function.

# The IF statement

Making decisions is at the core of most computer programs and in BASIC that is usually done with the IF statement. This is written almost like an English sentence:
IF condition THEN action
The condition is usually a comparison such as equals, less than, more than, etc. For example:
IF Temp < 25 THEN PRINT "Cold"
Temp would be a variable holding the current temperature (in ºC).
There are a range of tests that you can make:
=
<
>

equals
less than
greater than

<>
<=
>=

not equal
less than or equals
greater than or equals

You can also add an ELSE clause which will be executed if the initial condition tested false. For example, this will execute different actions when the temperature is under 25 or 25 or more:

IF Temp < 25 THEN PRINT "Cold" ELSE PRINT "Hot"

The previous examples all used single line IF statements but you can also have multiline IF statements. They look like this:

IF condition THEN
TrueActions
ENDIF

Or, if you also want to take some actions if false:

IF condition THEN
TrueActions
ELSE
FalseActions
ENDIF

Unlike the single line IF statement you can have many true actions with each on their own line and similarly many false actions. Generally the single line IF statement is handy if you have a simple action that needs to be taken while the multiline version is much easier to understand if the actions are numerous and more complicated.
An example of a multiline IF statement with more than one action is:

IF Temp < 25 THEN
PRINT "Cold"
TurnRedLightOff
ELSE
PRINT "Hot"
ft-RPI-sa Controller | Seite 18

TurnRedLightOn
ENDIF

Note that in the above example each action is indented to show what part of the IF structure it belongs to. Indenting is not mandatory but it makes a program much easier to understand for someone who is not familiar with it and therefore it is highly recommended. You will find that this tutorial uses indenting in all examples for this reason.
In a multiline IF statement you can make additional tests using the ELSE IF command. This is best explained by using an example:

IF Temp < 0 THEN
PRINT “Freezing”
ELSE IF Temp < 25 THEN
PRINT “Cold”
ELSE IF Temp < 40 THEN
PRINT “Warm”
ELSE
PRINT “Hot”
ENDIF

The ELSE IF can use the same tests as an ordinary IF (ie, <, <=, etc) but that test will only be made
if the preceding test was false. So, for example, you will only get the message Warm if Temp < 0 failed, and Temp < 25 failed but Temp < 40 was true. The final ELSE will catch the case
where all the tests were false.
An expression like Temp < 25 is evaluated by MMBasic as either true or false with true having a value of one and false zero. You can see this if you entered the following at the console:

PRINT 30 > 20

MMBasic will print 1 meaning that the value is true and similarly the following will print 0 meaning that the expression evaluated to false.

PRINT 30 < 20

The IF statement does not really care about what the condition actually is, it just evaluates the condition and if the result is zero it will take that as false and if non zero it will take it as true. This allows for some handy shortcuts. For example, if SwitchOn is a variable that is true (non zero) when some switch is turned on the following can be used to make a decision based on that value: IF SwitchOn THEN …do something…
FOR Loops
Another common requirement in programming is repeating a set of actions. For instance, you might want to step through all seven days in the week and perform the same function for each day. BASIC provides the FOR loop construct for this type of job and it works like this:

FOR day = 1 TO 7

Do something based on the value of ‘day’

NEXT day

This starts by creating the variable day and assigning the value of 1 to it. The program then will execute the following statements until it comes to the NEXT statement. This tells the BASIC

ft-RPI-sa Controller | Seite 19

interpreter to increment the value of day, go back to the previous FOR statement and re-execute the
following statements a second time. This will continue looping around until the value of day exceeds 7 and the program will then exit the loop and continue with the statements following the NEXT statement.

As a simple example, you can print the numbers from one to ten like this:
FOR nbr = 1 TO 10
PRINT nbr,;
NEXT nbr
The comma at the end of the PRINT statement tells the interpreter to tab to the next tab column after printing the number while the semicolon will leave the cursor on this line rather than automatically moving to the next line. As a result the numbers will be printed in neat columns across the page. Try it on a ft-RPI-sa, use the EDIT command to enter the short program listed above then press the F2 key to save and run it.
The FOR loop also has a couple of extra tricks up it sleeve. You can change the amount that the variable is incremented by using the STEP keyword. So, for example, the following will print just the odd numbers:

FOR nbr = 1 TO 10 STEP 2
PRINT nbr,;
NEXT nbr

The value of the step (or increment value) defaults to one if the STEP keyword is not used but you can set it to whatever number you want.
When MMBasic is incrementing the variable it checks to see if the variable has exceeded the TO value and, if it has, it will exit from the loop. So, in the above example, the value of nbr will reach nine and it will be printed but on the next loop nbr will be eleven and at that point execution will leave the loop. This test is also applied at the start of the loop (ie, if in the beginning the value of the variable exceeds the TO value the loop will never be executed, not even once).
By setting the STEP value to a negative number you can use the FOR loop to step down from a high number to low. For example, the following will print the numbers from 1 to 10 in reverse:

FOR nbr = 10 TO 1 STEP -1
PRINT nbr,;
NEXT nbr

# Multiplication Table

To further illustrate how loops work and how useful they can be, the following short program will use the FOR loop to print out the multiplication table that we all learnt at school. The program for this is not complicated:

FOR nbr1 = 1 to 10
FOR nbr2 = 1 to 10
PRINT nbr1 * nbr2,;
NEXT nbr2
PRINT
NEXT nbr1

The output will be similar to the screen grab below, which also shows a listing of the program.

ft-RPI-sa Controller | Seite 20

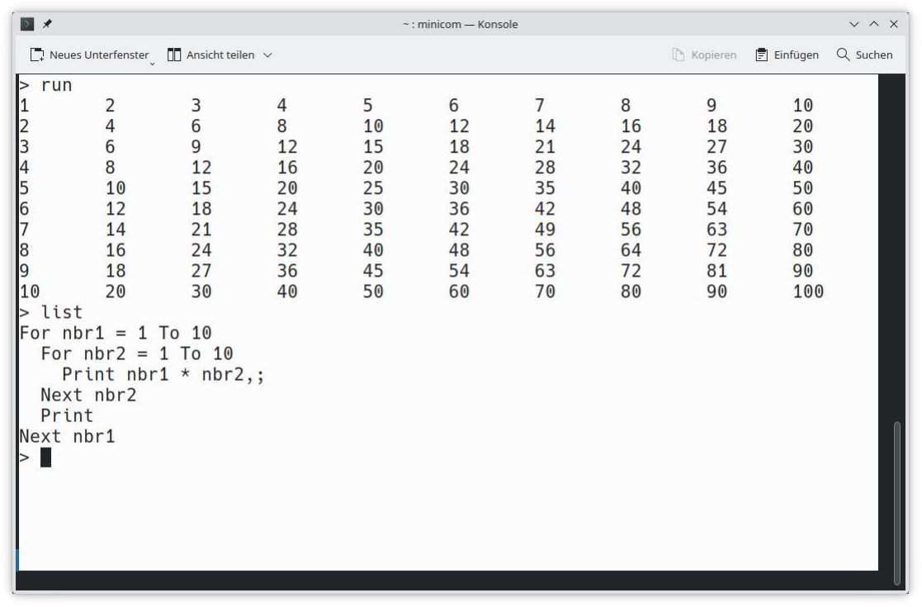
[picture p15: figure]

You need to work through the logic of this example line by line to understand what it is doing. Essentially it consists of one loop inside another. The inner loop, which increments the variable nbr2, prints one horizontal line of the table. When this loop has finished it will execute the following PRINT command which has nothing to print - so it will simply output a new line (ie, terminate the line printed by the inner loop).
The program will then execute another iteration of the outer loop by incrementing nbr1 and re-executing the inner loop again. Finally, when the outer loop is exhausted (when nbr1 exceeds
10) the program will reach the end and terminate.
One last point, you can omit the variable name from the NEXT statement and MMBasic will guess which variable you are referring to. However, it is good practice to include the name to make it easier for someone else who is reading the program. You can also terminate multiple loops using a comma separated list of variables in the NEXT statement. For example:

FOR var1 = 1 TO 5
FOR var2 = 10 to 13
PRINT var1 * var2
NEXT var1, var2

# DO Loops

Another method of looping is the DO…LOOP structure which looks like this:

DO WHILE condition
statement
statement
LOOP
ft-RPI-sa Controller | Seite 21

This will start by testing the condition and if it is true the statements will be executed until the
LOOP command is reached, at which point the condition will be tested again and if it is still true the loop will execute again. The ‘condition’ is the same as in the IF command (ie, X < Y). For
example, the following will keep printing the word "Hello" on the console for 4 seconds then stop:

Timer = 0
DO WHILE Timer < 4000
PRINT "Hello"
LOOP

Note that Timer is a function within MMBasic which will return the time in milliseconds since the timer was reset. A reset is done by assigning zero to Timer (as done above) or when powering up the ft-RPI-sa. We will cover the timer in more detail later.
A variation on the DO-LOOP structure is the following:

DO
statement
statement
LOOP UNTIL condition

In this arrangement the loop is first executed once, the condition is then tested and if the condition is false, the loop will be repeatedly executed until the condition becomes true. Note that the test in LOOP UNTIL is the inverse of DO WHILE.
For example, similar to the previous example, the following will also print "Hello" for four seconds:

Timer = 0
DO
PRINT "Hello"
LOOP UNTIL Timer >= 4000

Both forms of the DO-LOOP essentially do the same thing, so you can use whatever structure fits with the logic that you wish to implement.
Finally, it is possible to have a DO Loop that has no conditions at all – ie,

DO
statement
statement
LOOP

This construct will continue looping forever and you, as the programmer, will need to provide a way to explicitly exit the loop (the EXIT DO command will do this). For example:

Timer = 0
DO
PRINT "Hello"
IF Timer >= 4000 THEN EXIT DO LOOP

# Console Input

There are times where you would like to use the ft-RPI-sa as a straight computer with all of its

ft-RPI-sa Controller | Seite 22

input coming from the console and its output going to the same place. For that to work you need to capture keystrokes from the console and this can be done with the INPUT command. In its simplest
form the command is:

INPUT var

This command will print a question mark on the console's screen and wait for a number to be entered followed by the Enter key. That number will then be assigned to the variable var.

For example, the following program extends the expression for finding the hypotenuse of a triangle by allowing the user to enter the lengths of the other sides from the console.

PRINT "Length of side 1"
INPUT a
PRINT "Length of side 2"
INPUT b
PRINT "Length of the hypotenuse is " SQR(a * a + b * b)

This is a screen capture of a typical session:

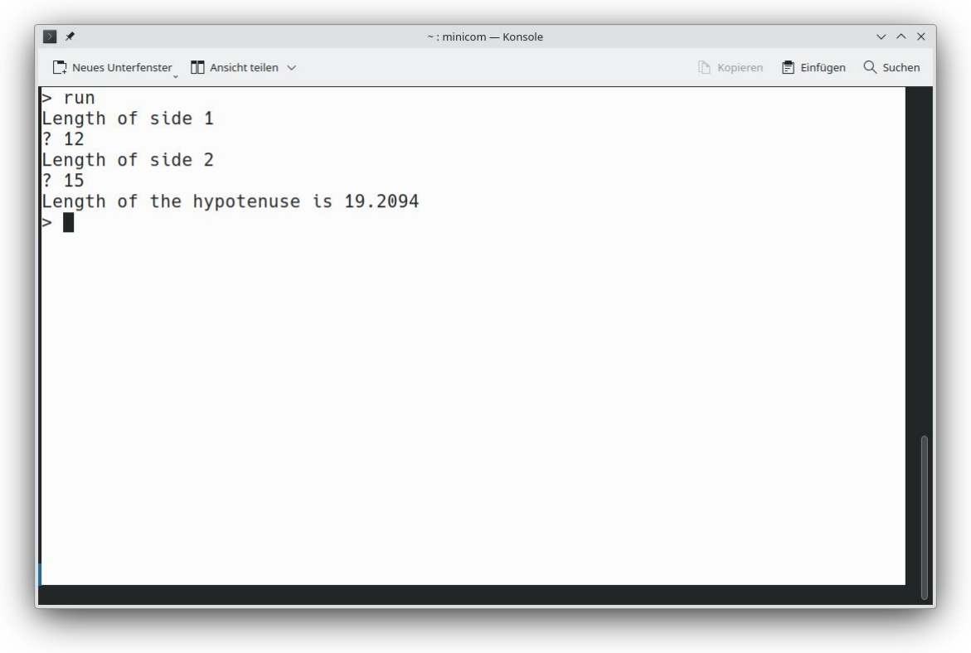
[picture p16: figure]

The INPUT command can also print your prompt for you, so that you do not need a separate PRINT
command. For example, this will work the same as the above program:

INPUT "Length of side 1"; a

ft-RPI-sa Controller | Seite 23

INPUT "Length of side 2"; b
PRINT "Length of the hypotenuse is " SQR(a * a + b * b)
Finally, the INPUT command will allow you to input a series of numbers separated by commas with each number being saved in different variables. For example:

INPUT "Enter the length of the two sides: ", a, b
PRINT "Length of the hypotenuse is " SQR(a * a + b * b)

If the user entered 12,15 the number 12 would be saved in the variable a and 15 in b.
Another method of getting input from the console is the LINE INPUT command. This will get the whole line as typed by the user and allocate it to a string variable. Like the INPUT command you can also specify a prompt. This is a simple example:

LINE INPUT "What is your name? ", s$
PRINT "Hello " s$

We will cover string variables in the next chapter but for the moment you can think of them as a variable that holds a sequence of one or more characters. If you ran the above program and typed in
John when prompted the program would respond with Hello John.
Sometimes you do not want to wait for the user to hit the enter key, you want each character as it is
typed in. This can be done with the INKEY$ function which will return the value of the character as a string (also covered in the next chapter).
ft-RPI-sa Controller | Seite 24

# GOTO and Labels

One method of controlling the flow of the program is the GOTO command. This essentially tells MMBasic to jump to another part of the program and continue executing from there. The target of the GOTO is a label and this needs to be explained first.
A label is an identifier that marks part of the program. It must be the first thing on the line and it must be terminated with the colon (:) character. The name that you use can be up to 32 characters long and must follow the same rules for a variable's name. For example, in the following program line LoopBack is a label:

LoopBack: a = a + 1

When you use the GOTO command to jump to that particular part of the program you would use the
command like this:

GOTO LoopBack

To put all this into context the following program will print out all the numbers from 1 to 10:

z = 0
LoopBack: z = z + 1
PRINT z
IF z < 10 THEN GOTO LoopBack

The program starts by setting the variable z to zero then incrementing it to 1 in the next line. The value of z is printed and then tested to see if it is less than 10. If it is less than 10 the program execution will jump back to the label LoopBack where the process will repeat. Eventually the value of z will be more than 10 and the program will run off the end and terminate.
Note that a FOR loop can do the same thing (and is simpler) so this example is purely designed to illustrate what the GOTO command can do.
In the past the GOTO command gained a bad reputation. This is because using GOTOs it is possible to create a program that continuously jumps from one point to another (often referred to as
"spaghetti code") and that type of program is almost impossible for another programmer to understand. With constructs like the multiline IF statements the need for the GOTO statement has been reduced and it should used be only when there is no other way of changing the program's flow.

# Testing for Prime Numbers

The following is a simple program which brings together many of the programming features previously discussed.

DO
InpErr:
PRINT
INPUT "Enter a number: "; a
IF a < 2 THEN
PRINT "Number must be equal or greater than 2" GOTO InpErr
ft-RPI-sa Controller | Seite 25

ENDIF
Divs = 0
FOR x = 2 TO SQR(a)
r = a/x
IF r = FIX(r) THEN Divs = Divs + 1 NEXT x
PRINT a " is ";
IF Divs > 0 THEN PRINT "not ";
PRINT "a prime number."
LOOP

This will first prompt (on the console) for a number and, when it has been entered, it will test if that number is a prime number or not and display a suitable message.
It starts with a DO Loop that does not have a condition – so it will continue looping forever. This is what we want. It means that when the user has entered a number, it will report if it is a prime number or not and then loop around and ask for another number. The way that the user can exit the
program (if they wanted to) is by typing the break character (normally CTRL-C).

The program then prints a prompt for the user which is terminated with a semicolon character. This means that the cursor is left at the end of the prompt for the INPUT command which will get the number and store it in the variable a.

Following this the number is tested. If it is less than 2 an error message will be printed and the program will jump backwards and ask for the number again.

We are now ready to test if the number is a prime number. The program uses a FOR loop to step through the possible divisors testing if each one can divide evenly into the entered number. Each time it does the program will increment the variable Divs. Note that the test is done with the function FIX(r) which simply strips off any digits after the decimal point. So, the condition
r = FIX(r) will be true if r is an integer (ie, has no digits after the decimal point).

Finally, the program will construct the message for the user. The key part is that if the variable Divs is greater than zero it means that one or more numbers were found that could divide evenly into the test number. In that case the IF statement inserts the word "not" into the output message. For example, if the entered number was 21 the user will see this response:
21 is not a prime number.

This is the result of running the program and some of the output:

ft-RPI-sa Controller | Seite 26

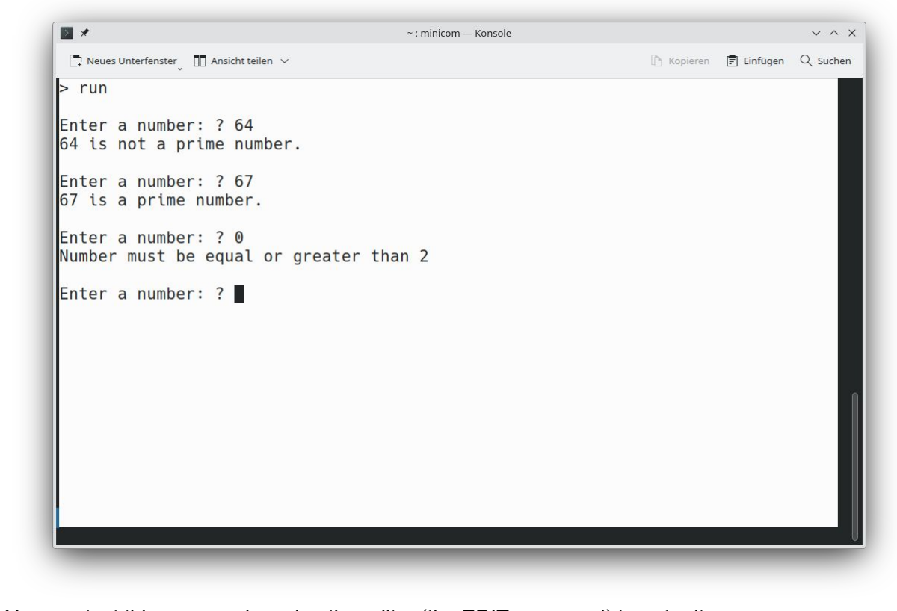
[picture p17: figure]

You can test this program by using the editor (the EDIT command) to enter it.

Using your newly learned skills you could then have a shot at making it more efficient. For example,
because the program counts how many times a number can be divided into the test number it takes a
lot longer than it should to detect a non prime number. The program would run much more efficiently if it jumped out of the FOR loop at the first number that divided evenly. You could use the GOTO command to do this or you could use the command EXIT FOR – that would cause the FOR loop to terminate immediately.

Other efficiencies include only testing the division with odd numbers (by using an initial test for an even number then starting the FOR loop at 3 and using STEP 2) or by only using prime numbers for the test (that would be much more complicated).

# Saving the Program

When you entered the program then saved it you might wonder where your program has actually been saved to. The answer is that it was automatically written into the dataflash memory of the S32K1xx chip. In fact, if you save a very large program you might see a delay of a second or two which is the time needed by MMBasic to transfer a large amount of data into the dataflash memory.

Flash memory is non volatile which means that it will retain its contents when the power is removed. This might not be important for a program that checks for prime numbers but if you have

ft-RPI-sa Controller | Seite 27

programmed the ft-RPI-sa to be the brains in your burglar alarm you will not want it to lose the program during a blackout.
The command MEMORY will report on how much memory was used by the program. With the above program it will display something like this:

Flash:
1K ( 1%) Program (19 lines)
59K (99%) Free
RAM:
1K ( 1%) 4 Variables
0K ( 0%) General
49K (99%) Free

As you can see, the program used little memory. This is another advantage of the ft-RPI-sa; the relatively huge memory space means that you can create large and complex programs and still run them on this small and inexpensive chip.

ft-RPI-sa Controller | Seite 28

# Advanced BASIC Programming

In the previous chapter we covered the fundamentals of BASIC programming, enough to write a small program to do a simple job. But BASIC has additional features that become important
when you are constructing a more complex program and we will cover these in this chapter.
As stressed before, this tutorial is not intended as a comprehensive manual and as such there are many more specialized features that are not covered here. To discover these it is recommended that you download the Micromite User Manual from: http://geoffg.net/micromite.html

# Utility Commands

Before we go much further we should discuss some of the utility commands and features of MMBasic that help you manage and run your program.
The first is the comment which is any text that follows the single quote character ('). A comment can be placed anywhere and extends to the end of the line. If MMBasic runs into a comment it will just skip to the end of it (ie, it does not take any action regarding a comment).
Comments should be used to explain non obvious parts of the program and generally inform someone who is not familiar with the program how it works and what it is trying to do. Remember that after only a few months a program that you have written will have faded from your mind and will look strange when you pick it up again. For this reason you will thank yourself later if you use plenty of comments.
The following are some examples of comments:

' calculate the hypotenuse
PRINT SQR(a * a + b * b)

or

INPUT var ' get the temperature

We have covered the EDIT command which will run the internal ft-RPI-sa program editor. Other useful commands are LIST which will list your program on the console (pausing every 24 lines) and the RUN command which will start your program running.
If you want to completely clear the program in memory you can use the NEW command which will erase everything leaving you with the maximum free program memory. The CLEAR command will do the same for any variables (ie, delete them and recover the memory). As shown before, the MEMORY command will list how much memory is currently being used.
The TRACE command is useful if you are trying to work out what your program is doing wrong. TRACE ON will cause MMBasic to list the line number of each statement as it is executed and this can help you trace the program flow. TRACE OFF will stop this feature. This command can also be embedded in your program so you can turn on tracing for short sections of code if you wish. Finally there is the OPTION command as mentioned in chapter 2. This takes many forms and using
it you can change many settings within MMBasic including how programs are listed, the attached devices (such as LCD panels), how your program will be run and much more.
ft-RPI-sa Controller | Seite 29

# Arrays

An array is something which you will probably not think of as useful at first glance but when you do need to use them you will find them very handy indeed.
An array is best thought of as a row of letterboxes for a block
of units or condos as shown on the right. The letterboxes are
all located at the same address and each box represents a

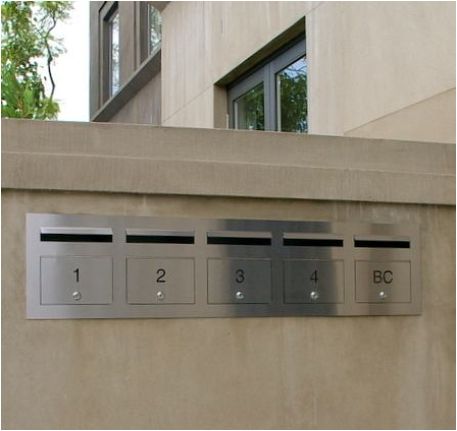
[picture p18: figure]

unit or condo at that address. You can place a letter in the box for unit one, or unit two, etc.

Similarly an array in BASIC is a single variable with multiple sub units (called elements in BASIC) which are numbered. You can place data in element one, or element two, etc. In BASIC an array is created by the DIM command, for example:

DIM numarr(300)

This created an array with the name of numarr and containing 301 elements (think of them as letterboxes). By default an array will start from zero so this is why there is an extra element making the total 301. To specify a specific element in the array (ie, a specific letterbox) you use an index which is simply the number of the array element that you wish to access. For example, if you want to set element number 100 in this array to (say) the number 876, you would do it this way:

numarr(100) = 876

Normally the index to an array is not a constant number as shown here but a variable which can be changed to access different array elements.
As an example of how you might use an array, consider the case where you would like to record the
temperature for each day of the year and, at the end of the year, calculate the overall average. You could use ordinary variables to record the temperature for each day but you would need 365 of them
and that would make your program unwieldy indeed. Instead, you could define an array to hold the values like this:

DIM days(365)

Every day you would need to save the temperature in the correct location in the array. If the number
of the day in the year was held in the variable doy and the maximum temperature was held in the variable maxtemp you would save the reading like this:

days(doy) = maxtemp

At the end of the year it would be simple to calculate the average for the year:

total = 0
FOR i = 1 to 365
total = total + days(i)
NEXT i
PRINT "Average is:" total / 365
ft-RPI-sa Controller | Seite 30

This is much easier than adding up and averaging 365 individual variables.

The above array was single dimensioned but you can have multiple dimensions. Reverting to our analogy of letterboxes, an array with
two dimensions could be thought of as a block of flats with multiple floors.
A block could have a row of four letter boxes for level one, another row of four boxes for level two, and so on. To place a letter in a letterbox you need to specify the floor number and the unit number on that floor.

In BASIC the array element is specified using two indices separated by a comma. For example:

LetterBox(floor, unit)

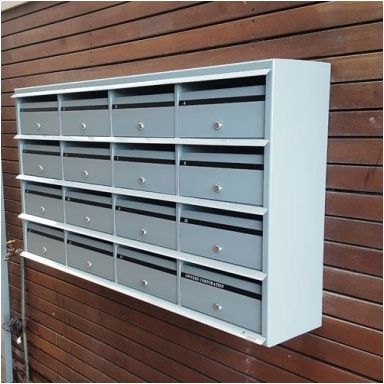
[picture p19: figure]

As a practical example, assume that you needed to record the maximum temperature for each day over five years. To do this you could dimension the array as follows:

DIM days(365, 5)

The first index is the day in the year and the second is a number representing the year. If you wanted to set day 100 in year 3 to 24 degrees you would do it like this:

days(100, 3) = 24

In MMBasic you can have up to eight dimensions and the maximum size of an array is only limited by the amount of free RAM that is available in the ft-RPI-sa.

# Integers

So far all the numbers and variables that we have been using have been floating point. As explained before, floating point is handy because it will track digits after the decimal point and when you use division it will return a sensible result. So, if you just want to get things done and are not concerned with the details you should stick to floating point.
However, the limitation of floating point is that it stores numbers as an approximation with an accuracy of only 7 or 8 digits in the processor.
For example, if you stored the number 1234.56789 in a floating point variable on the ft-RPI-sa then printed it out you will find that the value stored in the variable is actually 1234.57.
The limit on the accuracy of floating point can cause confusion for new programmers. For example, a beginner might write the following program for the ft-RPI-sa and be surprised
when the value of F does not change.

F = 1234.5
PRINT F
F = F + 0.0001
PRINT F

Most times this characteristic of floating point numbers is not a problem but there are some cases where you need to accurately store large numbers. Examples include tracking a GPS location on the planet's surface or interfacing with digital frequency synthesisers.

ft-RPI-sa Controller | Seite 31

As another example, let us say that you want to manipulate time accurately so that you can compare two different date/times to work out which one is earlier. The easy way to do this is to convert the date/time to the number of seconds since some date (say 1st Jan 1900) - then finding the earliest of the two is just a matter of using an arithmetic compare in an IF statement.
The problem is that the number of seconds since that date would far exceed the accuracy range of floating point variables and this is where integer variables come in. An integer variable in MMBasic can accurately hold very large numbers to over nine million million million (or
±9223372036854775807 to be precise).

The downside of using an integer is that it cannot store fractions (ie, numbers after the decimal point). Any calculation that produces a fractional result will be rounded up or down to the nearest whole number when assigned to an integer.
It is easy to create an integer variable, just add the percent symbol (%) as a suffix to a variable name. For example, sec% is an integer variable. Within a program you can mix integers and floating point and MMBasic will make the necessary conversions but if you want to maintain the full accuracy of integers you should avoid mixing the two.
Just like floating point you can have arrays of integers with up to eight dimensions, all you need to do is add the percent character as a suffix to the array name. For example: days%(365, 5). Beginners often get confused as to when they should use floating point or integers and the answer is simple… always use floating point unless you need a very high level of accuracy in the resulting number. This does not happen often but when you need them you will find that integers are a lifesaver.

# Strings

Strings are another variable type (like floating point and integers). Strings are used to hold a sequence of characters. For example, in the command:

PRINT "Hello"

The string "Hello" is a string constant. Note that a constant is something that does not change (as against a variable, which can) and that string constants are always surrounded by double quotes. String variables names use the dollar symbol ($) as a suffix to identify them as a string instead of a normal floating point variable and you can use ordinary assignment to set their value. The following are examples (note that the second example uses an array of strings):

Car$ = "Holden"
Country$(12) = "India"
Name$ = "Fred"

You can also join strings using the plus operator:

Word1$ = "Hello"
Word2$ = "World"
Greeting$ = Word1$ + " " + Word2$

In which case the value of Greeting$ will be "Hello World".
Strings can also be compared using operators such as = (equals), <> (not equals), < (less than), etc.
For example:

IF Car$ = "Holden" THEN PRINT "Was an Aussie made car"

ft-RPI-sa Controller | Seite 32

The comparison is made using the full ASCII character set so a space will come before a printable character. Also the comparison is case sensitive so 'holden' will not equal "Holden". Using the function UCASE() to convert the string to upper case you can have a case insensitive comparison. For example:

IF UCASE$(Car$) = "HOLDEN" THEN PRINT "Was an Aussie made car"

You can have arrays of strings but you need to be careful when you declare them as you can rapidly
run out of RAM (general memory used for storing variables, etc). This is because MMBasic will by default allocate 255 bytes of RAM for each element of the array. For example, a string array with 100 elements will by default use 25K of RAM. To alleviate this you can use the LENGTH qualifier to limit the maximum size of each element. For instance, if you know that the maximum length of any string that will be stored in the array will be less than 20 characters you can use the following declaration to allocate just 20 bytes for each element:

DIM MyArray$(100) LENGTH 20

The resultant array will only use 2K of RAM.

# Manipulating Strings

String handling is one of MMBasic's strengths and using a few simple functions you can pull apart and generally manipulate strings.
The basic string functions are:
LEFT$(string$, nbr ) | Returns a substring of string$ with nbr of characters from the left (beginning) of the string.
RIGHT$(string$, nbr ) | Same as the above but return nbr of characters from the right (end) of the string.
MID$(string$, pos, nbr ) | Returns a substring of string$ with nbr of characters starting from the character pos in the string (ie, the middle of the string).

For example if S$ = "This is a string"
Then: R$ = LEFT$(S$, 7)
would result in the value of R$ being set to: "This is" and: R$ = RIGHT$(S$, 8)
would result in the value of R$ being set to: "a string"
finally: R$ = MID$(S$, 6, 2)
would result in the value of R$ being set to: "is"
Note that in MID$() the first character position in a string is number 1, the second is number 2 and so on. So, counting the first character as one, the sixth position is the start of the word "is". Another useful function is:
INSTR(string$, pattern$ ) Returns a number representing the position at which pattern$
| occurs in string$.

This can be used to search for a string inside another string. The number returned is the position of the substring inside the main string. Like with MID$() the start of the string is position 1.
For example if S$ = "This is a string"
Then: pos = INSTR(S$, " ")
would result in pos being set to the position of the first space in S$ (ie, 5).
ft-RPI-sa Controller | Seite 33

INSTR() can be combined with other functions so this would return the first word in S$:

R$ = LEFT$(S$, INSTR(S$, " ") - 1)

There is also an extended version of INSTR():
INSTR(pos, string$, pattern$ ) Returns a number representing the position at which pattern$ occurs in string$ when starting the search at the character
position pos.
So we can find the second word in S$ using the following:

pos = INSTR(S$, " ")
R$ = LEFT$(S$, INSTR(pos + 1, S$, " ") - 1)

This last example is rather complicated so it might be worth working through it in detail so that you can understand how it works.
Note that INSTR() will return the number zero if the sub string is not found and that any string function will throw an error (and halt the program) if that is used as a character position. So, in a practical program you would first check for zero being returned by INSTR() before using that value. The section on serial communications in chapter 7 has a good example of using this function.

# Scientific Notation

Before we finish discussing data types we need to cover off the subject of floating point numbers and scientific notation.
Most numbers can be written normally, for example 11 or 24.5, but very large or small numbers are more difficult. For example, it has been estimated that the number of grains of sand on planet Earth
is 7500000000000000000. The problem with this number is that you can easily lose track of how many zeros there are in the number and consequently it is difficult to compare this with a similar sized number.
A scientist would write this number as 7.5 x 10¹⁸ which is called scientific notation and is much easier to comprehend.
MMBasic will automatically shift to scientific notation when dealing with very large or small floating point numbers. For example, if the above number was stored in a floating point variable the PRINT command would display the number as 7.5E+18 (this is BASIC’s way of representing 7.5 x 10¹⁸). As another example, the number 0.0000000456 would display as 4.56E-8 which is the same as 4.56 x 10⁻⁸
You can also use scientific notation when entering constant numbers in MMBasic. For example: SandGrains = 7.5E+18
MMBasic only uses scientific notation for displaying floating point numbers (not integers). For instance, if you assigned the number of grains of sand to an integer variable it would print out as a normal number (with lots of zeros).

# DIM Command

We have used the DIM command before for defining arrays but it can also be used to create ordinary variables. For example, you can simultaneously create four string variables like this:

DIM STRING Car, Name, Street, City

Note that because these variables have been defined as strings using the DIM command we do not
need the $ suffix, the definition alone is enough for MMBasic to identify their type. When you use
ft-RPI-sa Controller | Seite 34

these variables in an expression you also do not need the type suffix: Eg:

City = "Sydney"

You can also use the keyword INTEGER to define a number of integer variables and FLOAT to do the same for floating point variables. This type of notation can also be used to define arrays. For example:

DIM INTEGER seconds(200)

Another method of defining the variables type is to use the keyword AS. For example:

DIM Car AS STRING, Name AS STRING, Street AS STRING

This is the method used by Microsoft (MMBasic tries to maintain Microsoft compatibility) and it is useful if the variables have different types. For example:

DIM Car AS STRING, Age AS INTEGER, Value AS FLOAT

You can use any of these methods of defining a variable's type, they all act the same.
The advantage of defining variables using the DIM command is that they are clearly defined (preferably at the start of the program) and their type (float, integer or string) is not subject to misinterpretation. You can strengthen this by using the following commands at the very top of your program:

OPTION EXPLICIT
OPTION DEFAULT NONE

The first specifies to MMBasic that all variables must be explicitly defined using DIM before they can be used. The second specifies that the type of all variables must be specified when they are created.
Why are these two commands important?
They can help you to avoid a common programming error which is where you accidently misspell a variable's name. For example, your program might have the current temperature saved in a variable
called Temp but at one point you accidently misspell it as Tmp. This will cause MMBasic to automatically create a variable called Tmp and set its value to zero.
This is obviously not what you want and it will introduce a subtle error which could be hard to find – even if you were aware that something was not right. On the other hand, if you used the OPTION EXPLICIT command at the start of your program MMBasic would refuse to automatically create the variable and instead would display an error thereby saving you from a probable headache. For small, quick and dirty programs, it is fine to allow MMBasic to automatically create variables but in larger programs you should always disable this feature with OPTION EXPLICIT and strengthen it with OPTION DEFAULT NONE.
When a variable is created it is set to zero for float and integers and an empty string (ie, contains no
characters) for a string variable. You can set its initial value to something else when it is created using DIM. For example:

DIM FLOAT nbr = 12.56
DIM STRING Car = "Ford", City = "Perth"

You can also initialise arrays by placing the initialising values inside brackets like this:

ft-RPI-sa Controller | Seite 35

DIM s$(2) = ("zero", "one", "two")

Note that because arrays start from zero this array actually has three elements with the index numbers of 0, 1 and 2. This is why we needed three string constants to initialise it.

# Constants

A common requirement in programming is to define a variable that represents a value without the risk of the value being accidently changed - which can happen if standard variables were used for this purpose. These are called constants and they can represent pin numbers, signal limits, mathematical constants and so on.
You can create a constant using the CONST command. This defines an identifier that acts like a variable but is set to a value that cannot be changed. For example:

CONST BatteryVoltagePin = 26
CONST BatteryMinimum = 11.5

These constants can then be used in a program where they make more sense to the casual reader than simple numbers. For example:

IF PIN(BatteryVoltagePin) < BatteryMinimum THEN SoundAlarm

It is good programming practice to use constants for any fixed number that represents an important value. Normally they are defined at the start of a program where they are easy to see and conveniently located for another programmer to adjust (if necessary). Using the above as an example, you might replace the battery with a different technology and therefore you need to change the minimum battery voltage. That could be easily accomplished if you originally defined this value as a constant at the start of your program.

# Subroutines

A subroutine is a block of programming code which is self contained (like a module) and can be called from anywhere within your program. To your program it looks like a built in MMBasic command and can be used the same. For example, assume that you need a command that would signal an error by printing a message on the console. You could define the subroutine like this:

SUB ErrMsg
PRINT "Error detected"
END SUB

With this subroutine embedded in your program all you need to do is use the command ErrMsg whenever you want to display the message. For example:

IF A < B THEN ErrMsg

The definition of a subroutine can be anywhere in the program but typically it is at the end. If MMBasic runs into the definition while running your program it will simply skip over it.
The above example is fine enough but it would be better if a more useful message could be displayed, one that could be customised every time the subroutine was called. This can be done by passing a string to the subroutine as an argument (sometimes called a parameter).
In this case the definition of the subroutine would look like this:

SUB ErrMsg Msg$

ft-RPI-sa Controller | Seite 36

PRINT "Error: " + Msg$
END SUB

Then when you call the subroutine, you can supply the string to be printed on the command line of the subroutine. For example:

ErrMsg "Number too small"

When the subroutine is called like this the message "Error: Number too small" will be
printed on the console. Inside the subroutine Msg$ will have the value of "Number too small" and it will be concatenated in the PRINT statement to make the full error message.
A subroutine can have any number of arguments which can be float, integer or string with each argument separated by a comma. Within the subroutine the arguments act like ordinary variables but they exist only within the subroutine and will vanish when the subroutine ends. You can have variables with the same name in the main program and they will be hidden within the subroutine and be different from arguments defined for the subroutine.
The type of the argument to be supplied can be specified with a type suffix (ie, $, % or ! for string, integer and float). For example, in the following the first argument must be a string and the second an integer:

SUB MySub Msg$, Nbr%
…
END SUB

MMBasic will convert the supplied values if it can, so if your program supplied a floating point value as the second argument MMBasic will convert it to an integer. If MMBasic cannot convert the value it will display an error. For example, if you supplied a string for the second argument your program will stop with an error.
You do not have to use the type suffixes, you can instead define the type of the arguments using the
AS keyword similar to the way it is used in the DIM command. For example, the following is identical to the above example:

SUB MySub Msg AS STRING, Nbr AS INTEGER
…
END SUB

Of course, if you used only one variable type throughout the program and used OPTION DEFAULT to set that type you could ignore the question of variable types completely.
When a subroutine is called with an argument that is a variable (ie, not a constant or expression) MMBasic will create a corresponding variable within the subroutine that points back to this variable. Any changes to the variable representing the argument inside the subroutine will also change the variable used in the call. This is called passing arguments by reference.
This is best explained by example:
DIM MyNumber = 5 | ‘ set the variable to 5
CalcSquare MyNumber | ‘ the subroutine will square its value
PRINT MyNumber | ‘ this will print the number 25
END | ‘ square the argument and pass it back

SUB CalcSquare nbr
nbr = nbr * nbr
END SUB
ft-RPI-sa Controller | Seite 37

The subroutine CalcSquare will take its argument, square it and write it back to the variable representing the argument (nbr). Because the subroutine was called with a variable (MyNumber) the variable nbr will point back to MyNumber and any change to nbr will also change
MyNumber accordingly. As a result the PRINT statement will output 25.
Passing arguments by reference is handy because it allows a subroutine to pass back values to the
code that called it. However it can lead to trouble if a subroutine used the variable representing an argument as a general purpose variable and changed its value. Then, if it were called with a variable
as an argument, that variable would be inadvertently changed. For this reason you should avoid manipulating variables representing arguments inside a subroutine, instead assign the value to a local variable (see below) and manipulate that instead.
When you call a subroutine you can omit some (or all) of the parameters and they will take the value of zero (for floats or integers) or an empty string. This is handy as your subroutine can tell if a parameter is missing and act accordingly.
For example, here is our subroutine to generate an error message but this version can be used without specifying an error message as a parameter:

SUB ErrMsg Msg$
IF Msg$ = "" THEN
PRINT "Error detected"
ELSE
PRINT "Error: " + Msg$
ENDIF
END SUB

Within a subroutine you can use most features of MMBasic including calling other subroutines, IF…THEN commands, FOR…NEXT loops and so on. However one thing that you cannot do is jump out of a subroutine using GOTO (if you do the result will be undefined). Normally the subroutine will exit when the END SUB command is reached but you can also terminate the subroutine early by using the EXIT SUB command.

# Functions

Functions are similar to subroutines with the main difference being that a function is used to return a value in an expression. For example, if you wanted a function to convert a temperature from degrees Celsius to Fahrenheit you could define:

FUNCTION Fahrenheit(C)
Fahrenheit = C * 1.8 + 32
END FUNCTION

Then you could use it in an expression:

Input "Enter a temperature in Celsius: ", t PRINT "That is the same as" Fahrenheit(t) "F"

Or as another example:

IF Fahrenheit(temp) <= 32 THEN PRINT "Freezing"

You could also define the reverse:

ft-RPI-sa Controller | Seite 38

FUNCTION Celsius(F)
Celsius = (F - 32) * 0.5556
END FUNCTION

As you can see, the function name is used as an ordinary local variable inside the subroutine. It is only when the function returns that the value is made available to the expression that called it. The rules for the argument list in a function are similar to subroutines. The only difference is that parentheses are always required around the argument list when you are calling a function, even if there are no arguments (they are optional when calling a subroutine). Functions can also use LOCAL and STATIC variables just like subroutines.
To return a value from the function you assign a value to the function's name within the function. If the function's name is terminated with a type suffix (ie, $, a % or a !) the function will return that type (string, integer or float), otherwise it will return whatever the OPTION DEFAULT is set to. For example, the following function will return a string:

FUNCTION LVal$(nbr)
IF nbr = 0 THEN LVal$ = "False" ELSE LVal$ = "True"
END FUNCTION

You can explicitly specify the type of the function by using the AS keyword and then you do not need to use a type suffix (similar to defining a variable using DIM).
This is an example:

FUNCTION LVal(nbr) AS STRING
IF nbr = 0 THEN LVal = "False" ELSE LVal = "True"
END FUNCTION

In this case the type returned by the function LVal will be a string.
As for subroutines you can use most features of MMBasic within functions. This includes FOR…NEXT loops, calling other functions and subroutines, etc. Also, the function will return to the expression that called it when the END FUNCTION command is reached but you can also return early by using the EXIT FUNCTION command.

# Local Variables

Variables that are created using DIM or that are just automatically created are called global variables. This means that they can be seen and used anywhere in the program including within subroutines. However, inside a subroutine you will often need to use variables for various tasks that
are internal to the subroutine. In portable code you do not want the name you chose for such a variable to clash with a global variable of the same name. To this end you can define a variable using the LOCAL command within the subroutine.
The syntax for LOCAL is identical to the DIM command, this means that the variable can be an array, you can set the type of the variable and you can initialise it to some value.
For example, this is our ErrMsg subroutine that we used a few pages back but this time it has been extended to use a local variable for joining the error message strings.

SUB ErrMsg Msg$
LOCAL STRING tstr
tstr = "Error: " + Msg$
PRINT tstr
END SUB
ft-RPI-sa Controller | Seite 39

The variable tstr is declared as LOCAL within the subroutine, which means that (like the argument list) it will only exist within the subroutine and will vanish when the subroutine exits. You can have a global variable called tstr in your main program and it will be different from the variable tstr in the subroutine (in this case the global tstr will be hidden within the subroutine). You should always use local variables for operations within your subroutine because they help make the subroutine much more self contained and portable.

# Static Variables

LOCAL variables are reset to their initial values (normally zero or an empty string) every time the subroutine starts, however there are times when you would like the variable to retain its value between calls to the subroutine. This type of variable is defined with the STATIC command.
We can demonstrate how STATIC variables are useful by extending the ErrMsg subroutine to prevent duplicated calls to the subroutine repeatedly displaying the same message. For example, our program might call this subroutine from multiple places but if the message is the same in a number of subsequent calls we would like to see the message just once.
To keep track of the last message displayed we use a static variable called lastmsg. This will
hold the text of the last message and we can compare it to the current message text to determine if it
is different and therefore should be printed.
This is our new subroutine:

SUB ErrMsg Msg$
STATIC STRING lastmsg
LOCAL STRING tstr
IF Msg$ <> lastmsg THEN
tstr = "Error: " + Msg$
PRINT tstr
lastmsg = Msg$
ENDIF
END SUB

This would give just one message every time a call is made with a duplicate message text.
The STATIC command uses exactly the same syntax as DIM. This means that you can define different types of static variables including arrays and you can also initialise them to some value. The static variable is created on the first time the STATIC command is encountered and it is automatically set to zero (if a float or integer) or an empty string. On subsequent calls to the subroutine MMBasic will recognise that the variable has already been created and it will leave its value untouched (ie, whatever it was in the previous call). As with DIM you can also initialise a static variable to some value. For example:

STATIC INTEGER var = 123

On the first call (when the variable is created) it will be initialised to 123 but on subsequent calls it will keep whatever its value was previously set to.
Mostly static variables are used to keep track of the state of something while inside a subroutine. A state is a record of something that has happened previously. Examples include:
- Has the COM port already been opened?
- What steps in a sequence have we completed?
- What text has already been displayed?
Normally you will use global variables (created using DIM) to track a state but sometimes you want
ft-RPI-sa Controller | Seite 40

this to be contained within a subroutine and this is where static variables are valuable. Just like LOCAL the use of STATIC helps to make your subroutines more self contained and portable.

# Calculate Days

We have covered a lot of programming commands and techniques so far in this tutorial and, to give
an example of how they work together, the following is an example program that will calculate the number of days between two dates.
It works by getting two dates from the user at the console and then converting them to integers representing the number of days since 1900. With these two numbers a simple subtraction will give the number of days between them.

' Example program to calculate the number of days between two dates

OPTION EXPLICIT
OPTION DEFAULT NONE
DIM STRING s
DIM FLOAT d1, d2
DO
PRINT
PRINT "Enter the date as dd mmm yyyy" PRINT " First date";
INPUT s
d1 = GetDays(s)
IF d1 = 0 THEN PRINT "Invalid date!" : CONTINUE DO PRINT "Second date";
INPUT s
d2 = GetDays(s)
IF d2 = 0 THEN PRINT "Invalid date!" : CONTINUE DO PRINT "Difference is" ABS(d2 - d1) " days"
LOOP

' Calculate the number of days since 1/1/1900
FUNCTION GetDays(d$) AS FLOAT
LOCAL STRING Month(11) =
("jan","feb","mar","apr","may","jun","jul","aug","sep","oct","nov","dec") LOCAL FLOAT Days(11) = (0,31,59,90,120,151,181,212,243,273,304,334) LOCAL FLOAT day, mth, yr, s1, s2

' Find the separating space character within a date
s1 = INSTR(d$, " ")
IF s1 = 0 THEN EXIT FUNCTION
s2 = INSTR(s1 + 1, d$, " ")
IF s2 = 0 THEN EXIT FUNCTION

' Get the day, month and year as numbers
day = VAL(MID$(d$, 1, s2 - 1)) - 1
IF day < 0 OR day > 30 THEN EXIT FUNCTION
FOR mth = 0 TO 11
IF LCASE$(MID$(d$, s1 + 1, 3)) = Month(mth) THEN EXIT FOR NEXT mth
IF mth > 11 THEN EXIT FUNCTION
ft-RPI-sa Controller | Seite 41

yr = VAL(MID$(d$, s2 + 1)) - 1900
IF yr < 1 OR yr >= 200 THEN EXIT FUNCTION

' Calculate the number of days including adjustment for leap years GetDays = (yr * 365) + FIX((yr - 1) / 4)
IF yr MOD 4 = 0 AND mth >= 2 THEN GetDays = GetDays + 1
GetDays = GetDays + Days(mth) + day
END FUNCTION

Note that the line starting LOCAL STRING Month(11) has been wrapped around because of the limited page width – it is one line as follows:

LOCAL STRING Month(11) = ("jan","feb","mar","apr","may","jun","jul","aug","sep","oct","nov","dec")

ft-RPI-sa Controller | Seite 42

When this program is run it will ask for the two dates to be entered and you need to use the form of dd mmm yyyy. This screen capture shows what the running program will look like.
The main feature of the program is the user defined function
GetDays() which takes a string entered at the console, splits it into its day, month and year
components then calculates the number of days since 1st January 1900. This function is called
twice, once for the first date and
then again for the second date. It is

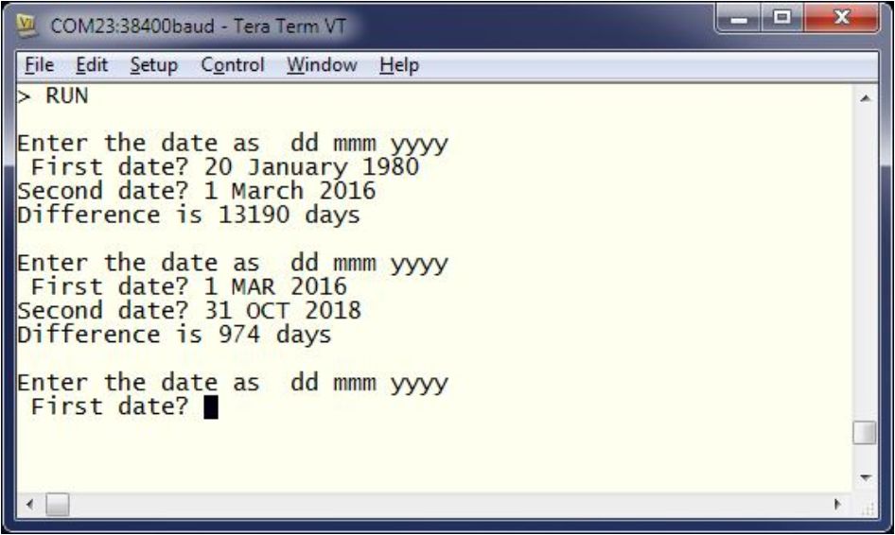
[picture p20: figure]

then just a matter of subtracting one date (in days) from the other to get the difference in days.
We will not go into the detail of how the calculations are made (ie, handling leap years) as that can be left as an exercise for the reader. However it is appropriate to point out some features of MMBasic that are used by the program.
It demonstrates how local variables can be used and how they can be initialised. In the function GetDays() two arrays are declared and initialised at the same time. These are just a convenient method of looking up the names of the months and the cumulative number of days for each month. Later in the function (the FOR loop) you can see how they make dealing with twelve different months quite efficient.
Another feature highlighted by this program is the string handling features of MMBasic. The INSTR() function is used to locate the two space characters in the date string and then later the MID$() function uses these to extract the day, month and year components of the date. The VAL() function is used to turn a string of digits (like the year) into a number that can be stored in a numeric variable.
Note that the value of a function is initialised to zero every time the function is run and unless it is set to some value it will return a zero value. This makes error handling easy because we can just exit the function if an error is discovered. It is then the responsibility of the calling program code to check for a return value of zero which signifies an error.
This program illustrates one of the benefits of using subroutines and functions which is that when written and fully tested they can be treated as a trusted "black box" that does not have to be opened.
For this reason functions like this should be the properly tested and then, if possible, left untouched (in case you add some error).
There are a few features of this program that we have not covered before. The first is the MOD operator which will calculate the remainder of dividing one number into another. For example, if you divided 4 into 15 you would have a remainder of 3 which is exactly what the expression 15 MOD 4 will return. The ABS() function is also new and will return its argument as a positive number (eg, ABS(-15) will return +15 as will ABS(15)).
The EXIT FOR command will exit a FOR loop even though it has not reached the end of its looping, EXIT FUNCTION will immediately exit a function even though execution has not reached the end of the function and CONTINUE DO will immediately cause the program to jump to the end of a DO loop and execute it again.
Why would this program be useful? Well some people like to count their age in days, that way every day is a birthday! You can calculate your age in days, just enter the date that you were born and today's date. That is not particularly useful but the program itself is valuable as it demonstrates many of the characteristics of programming in MMBasic. So, pull out the ft-RPI-sa User Manual and work your way through the program code – it should be a rewarding experience.
ft-RPI-sa Controller | Seite 43

# Good Programming Habits

Before we finish with the subject of BASIC programming it will be worth while providing some hints on how to write programs that are easy to understand and maintain. This can be more important than one might think. A poorly written program is more likely to contain bugs and people will be reluctant to try and fix such a program because the logic is hard to understand. You might think that this does not matter because you will be the only person to ever read the program. But your memory will fade over time and when you try to modify a program that you wrote (say) a year ago it will be the same as if it was written by a complete stranger who you will hope had followed these hints.

1. Use lots of comments. They are the first thing that people (including you) will read when they pick up your program and they are invaluable in rendering the program and its logic understandable. Even if no one else will read the program you will appreciate the comments in the future.
2. Use indenting to illustrate the logic of loops, multi line IF statements, subroutines, etc. Without indenting the casual reader would have to search many lines to determine when a block of code has terminated.
3. Keep the comments and indenting up to date. When modifying a program it is easy to forget that these features also need updating and nothing is worse than a misleading comment or indentation.
4. Define all variables using DIM or LOCAL statements at the start of the program, subroutine or function. Do not let variables be automatically created, instead use OPTION EXPLICIT and OPTION DEFAULT NONE.
5. Use variable names that make sense. For a simple loop you can use a short variable like 'spd' but for something important that is scattered throughout the program use a descriptive variable name such as 'MaxSpeedLimit'.
6. Define significant numbers as constants at the start of the program using the CONST command.
7. MMBasic does not worry about upper or lower case characters in identifiers (variable names, subroutine names, etc) but regardless, you should use a consistent case. For example, you can use either MaxSpeedLimit or maxspeedlimit in a program, but you should not use both.
8. Package unique and self contained pieces of code into a subroutine or function. These have limited entry/exit points which means that someone can read through such a module and more easily satisfy themselves that it is working correctly. From then on it can be treated as a trusted portion of code.
9. Don't use the GOTO command unless you absolutely have to. Features such as multiline IF statements, subroutines and functions are much easier to understand than a program which uses GOTOs to jump around.
10. Don't be obsessed with optimising your code to make it faster for MMBasic to interpret. MMBasic makes many optimisations of its own and anything that you do will have little effect on speed and may obscure the logic of the program. Normally only a very small part of a program needs to run fast and if that is the case that portion would be better being written in C which can be embedded in the BASIC program.

For a short program you can ignore many of these hints but for a large program they can be a huge help and may help prevent your hair turning prematurely grey if you need to modify your program in the future.

ft-RPI-sa Controller | Seite 44
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

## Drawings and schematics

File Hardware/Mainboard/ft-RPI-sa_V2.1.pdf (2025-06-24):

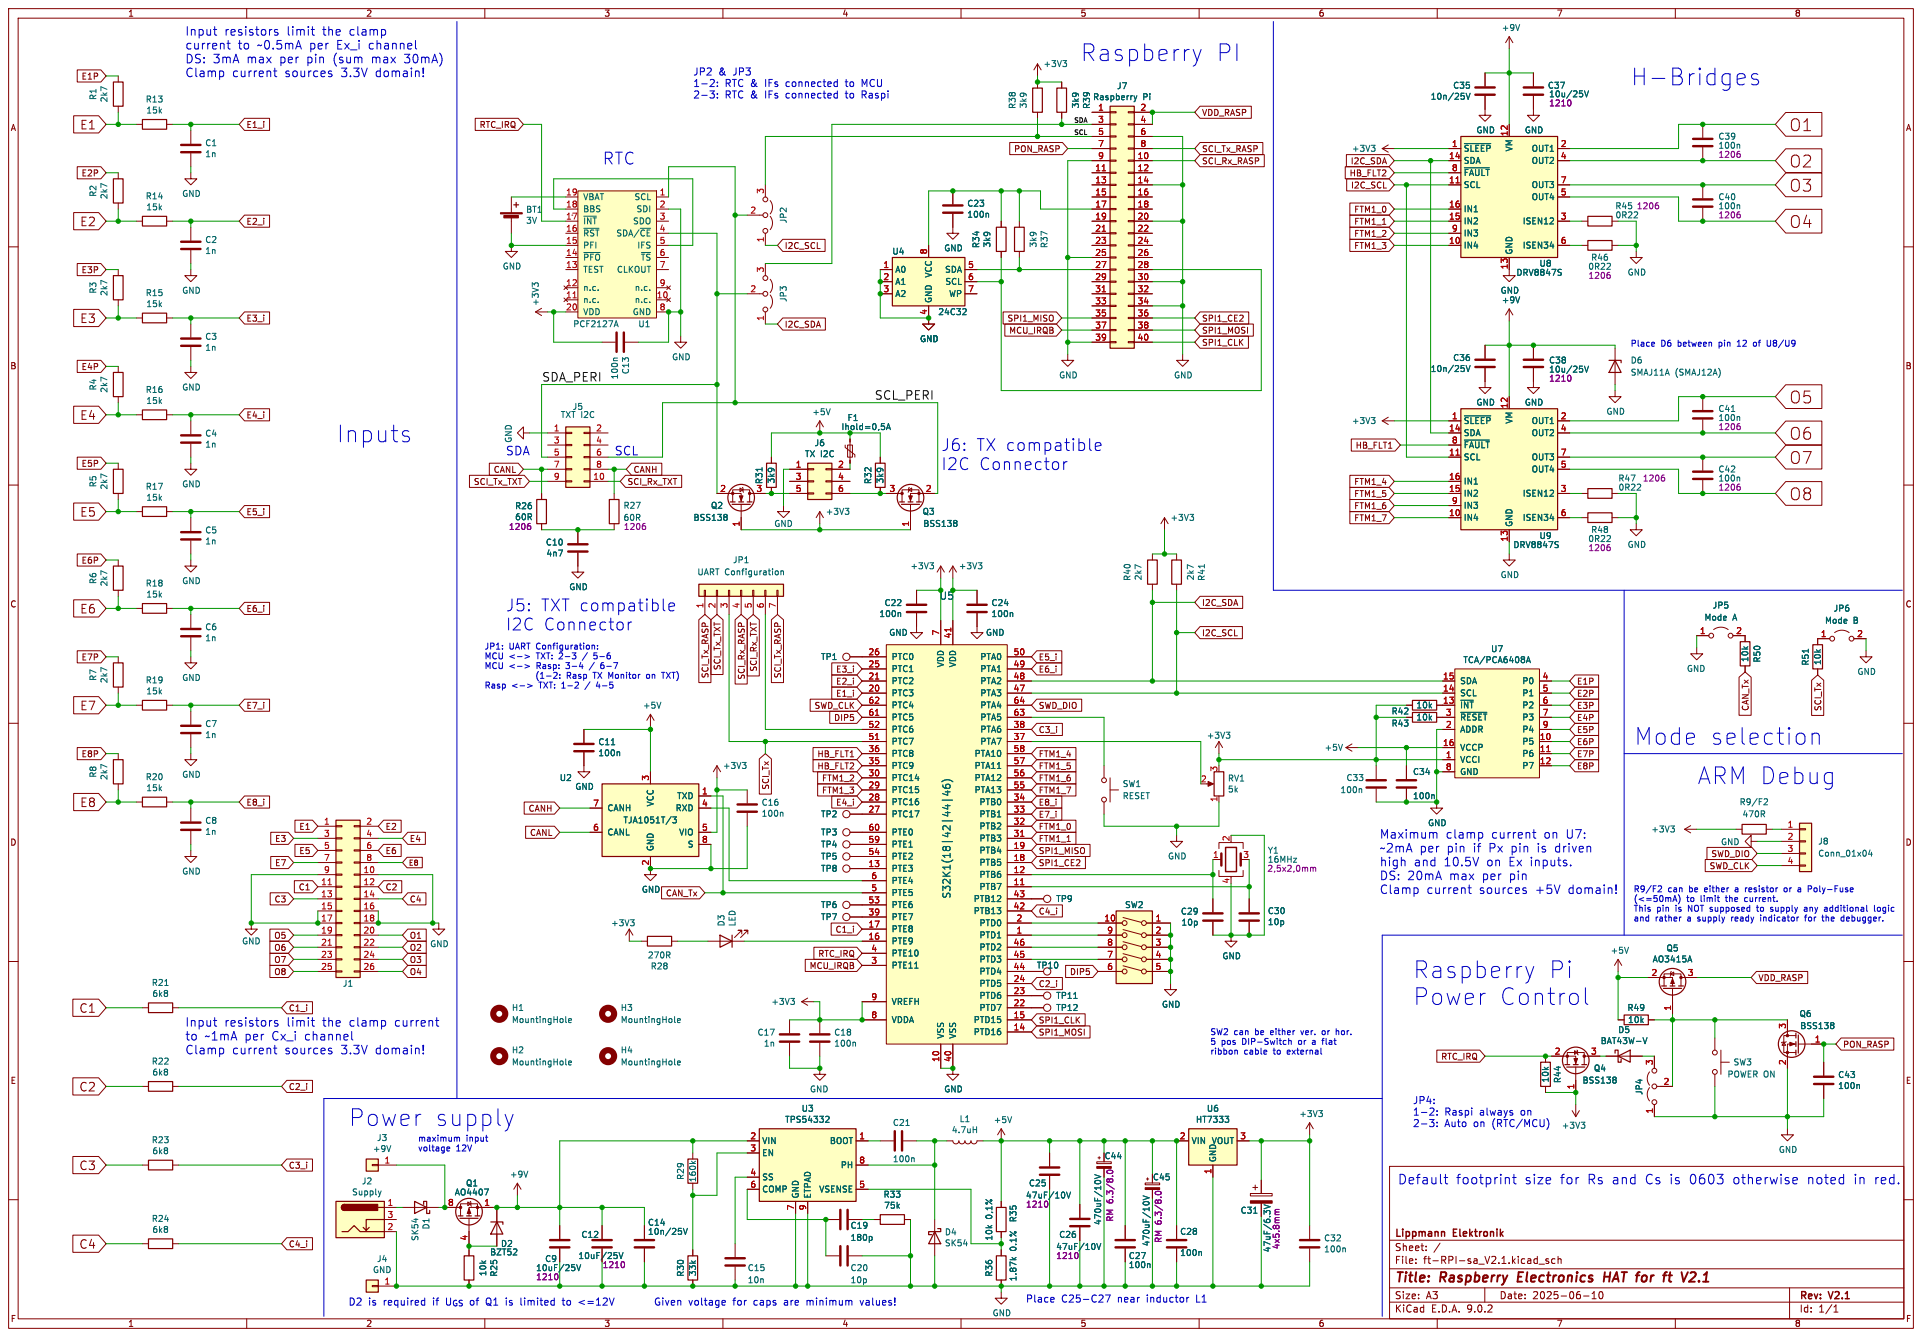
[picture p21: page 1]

current to ~0.5mA per Ex_i channel
DS: 3mA max per pin (sum max 30mA)
J7 Raspberry Pi GND

~{SLEEP} 1 SDA 14 ~{FAULT} 8 SCL 11

n.c. 10 GND 8 VBAT 19 BBS 18 ~{INT} 17 ~{RST} 16 PFI 15 ~{PFO} 14 TEST 13

1206 SCL 1 SDI 2 SDO 3 SDA/~{CE} 4

4 SDA 5 SCL 6 WP 7 GND R34 3k9 C23
100n GND

3 JP3 H4 MountingHole TP9 PTA0 50 PTA1 49 PTA2 48 PTA3 47 PTA4 64 PTA5 63 PTA6 38 PTA7 37 PTA10 58 PTA11 57 PTA12 56 PTA13 55 PTB0 34 PTB1 33 PTB2 32 PTB3 31 PTB4 19 PTB5 18 PTB6 12 PTB7 11 PTB12 43 PTB13 42 PTD0 2 PTD1 1 PTD2 46 PTD3 45 PTD4 44 PTD5 24 PTD6 23 PTD7 22 PTD15 15 PTD16 14 VDD 41 VSS 40 VDD

~2mA per pin if Px pin is driven
high and 10.5V on Ex inputs.
DS: 20mA max per pin
Clamp current sources +5V domain!

9 BOOT 1 PH 8 VSENSE 5 GND

Id: 1/1 Title: Raspberry Electronics HAT for ft V2.1

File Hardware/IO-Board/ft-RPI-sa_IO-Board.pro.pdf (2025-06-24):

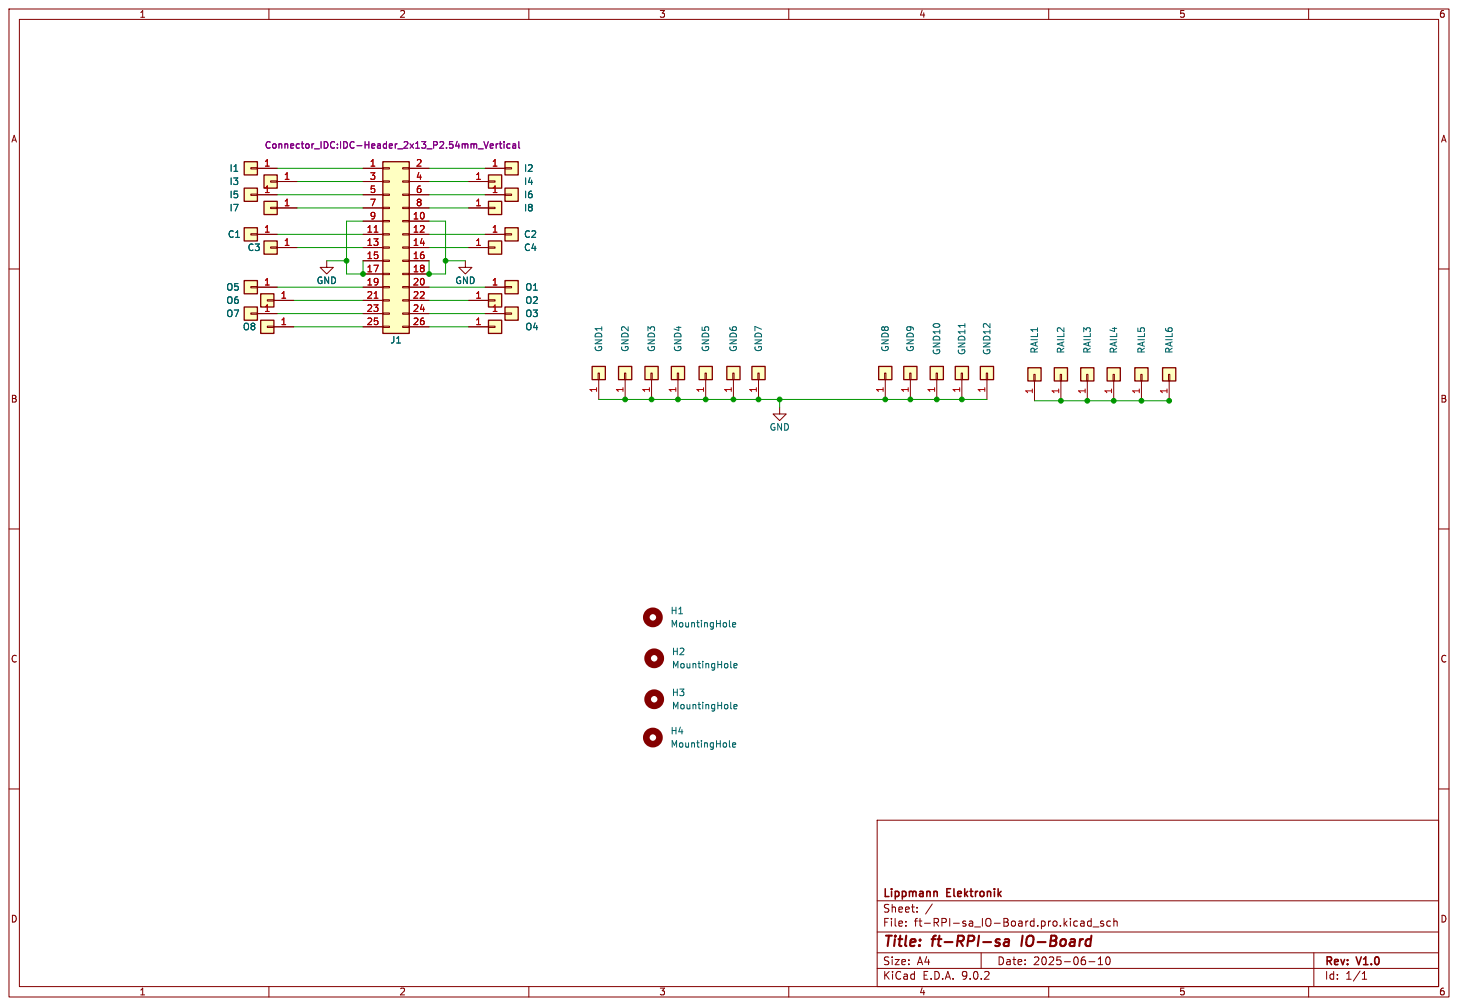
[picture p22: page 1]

11 11 | | 12 12
13 13 | | 14 14
15 15 | | 16 16
17 17 | | 18 18

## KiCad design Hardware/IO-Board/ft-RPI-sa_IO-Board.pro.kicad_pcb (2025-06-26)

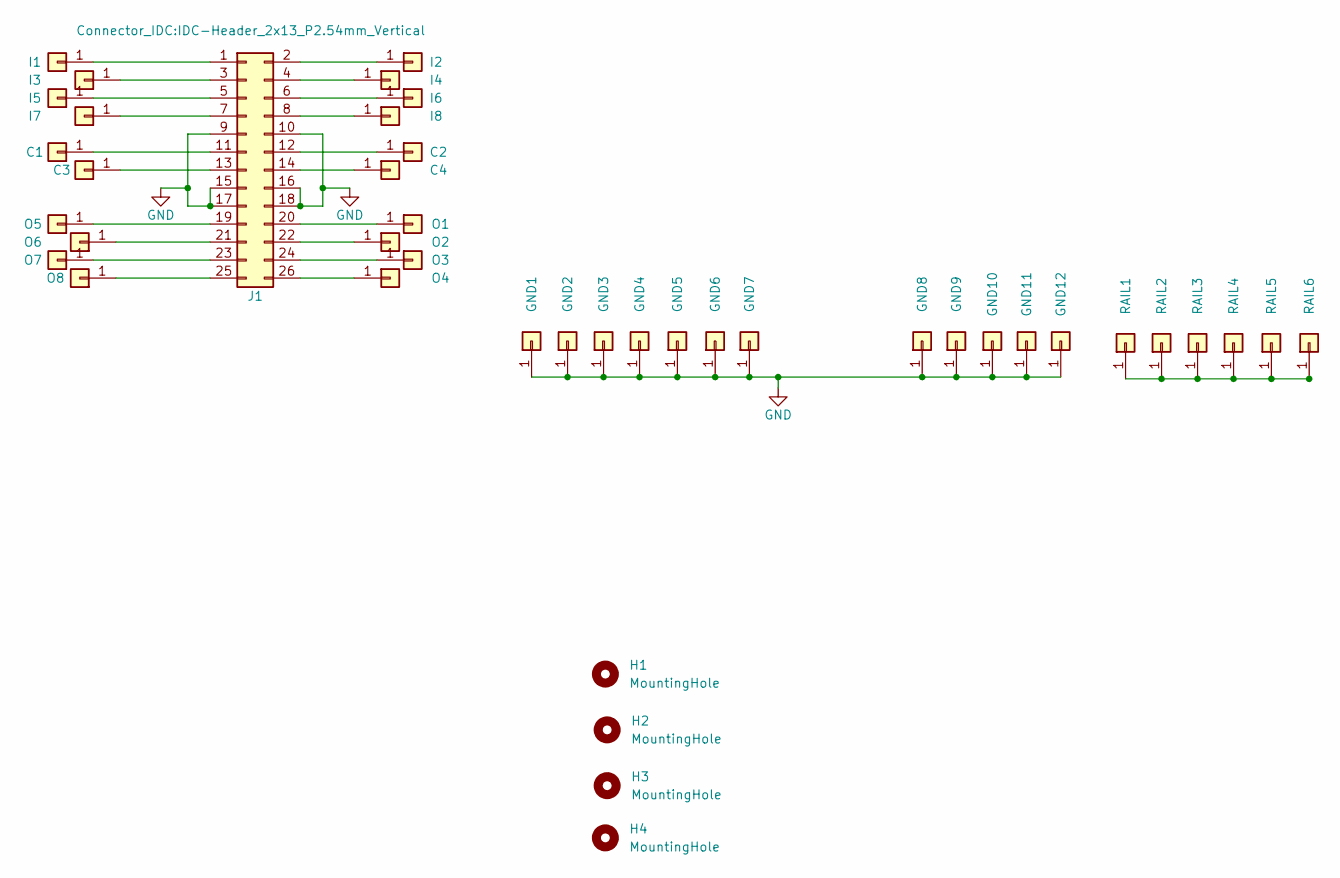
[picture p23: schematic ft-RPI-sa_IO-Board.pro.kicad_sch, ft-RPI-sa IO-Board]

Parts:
C1, C2, C3, C4: Conn_01x01; Bundhuelse_3mm
GND1, GND2, GND3, GND4, GND5, GND6, GND7, GND8, GND9, GND10, GND11, GND12: Conn_01x01; Bundhuelse_3mm
H1, H2, H3, H4: MountingHole; MountingHole_3.2mm_M3_DIN965
I1, I2, I3, I4, I5, I6, I7, I8: Conn_01x01; Bundhuelse_3mm
J1: Conn_02x13_Odd_Even; IDC-Header_2x13_P2.54mm_Vertical
O1, O2, O3, O4, O5, O6, O7, O8: Conn_01x01; Bundhuelse_3mm
RAIL1, RAIL2, RAIL3, RAIL4, RAIL5, RAIL6: Conn_01x01; Bundhuelse_3mm

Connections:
GND: GND1.1, GND2.1, GND3.1, GND4.1, GND5.1, GND6.1, GND7.1, GND8.1, GND9.1, GND10.1, GND11.1, GND12.1, J1.9, J1.10, J1.15, J1.16, J1.17, J1.18
unnamed: C1.1, J1.11
unnamed: C2.1, J1.12
unnamed: C3.1, J1.13
unnamed: C4.1, J1.14
unnamed: I1.1, J1.1
unnamed: I2.1, J1.2
unnamed: I3.1, J1.3
unnamed: I4.1, J1.4
unnamed: I5.1, J1.5
unnamed: I6.1, J1.6
unnamed: I7.1, J1.7
unnamed: I8.1, J1.8
unnamed: J1.19, O5.1
unnamed: J1.20, O1.1
unnamed: J1.21, O6.1
unnamed: J1.22, O2.1
unnamed: J1.23, O7.1
unnamed: J1.24, O3.1
unnamed: J1.25, O8.1
unnamed: J1.26, O4.1
unnamed: RAIL1.1, RAIL2.1, RAIL3.1, RAIL4.1, RAIL5.1, RAIL6.1

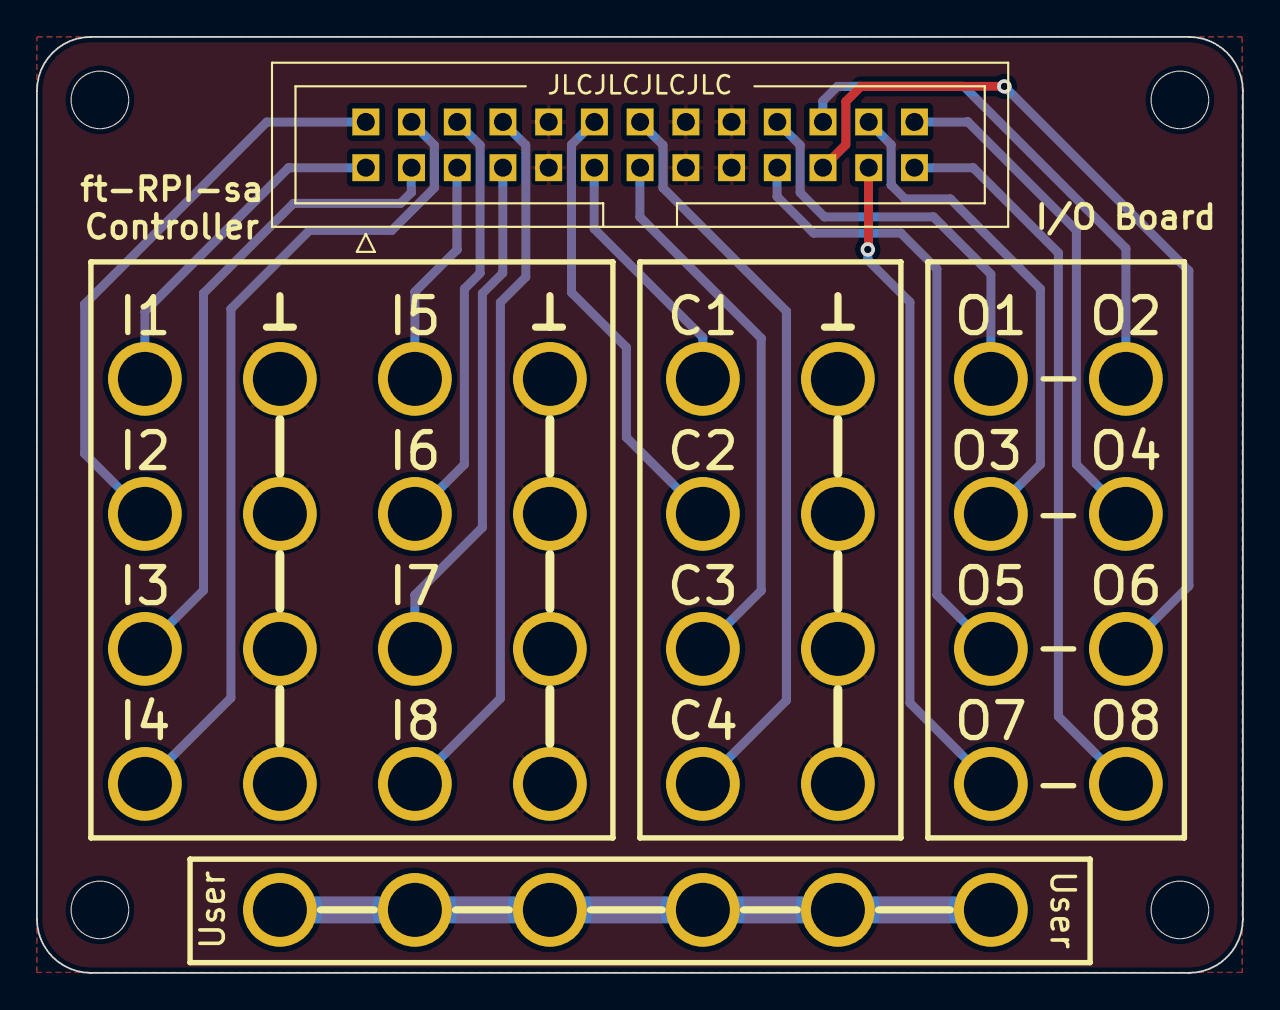
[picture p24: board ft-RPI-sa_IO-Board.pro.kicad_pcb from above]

Board: 2 copper layers, 67.0 x 52.0 mm, 43 parts (0 on the bottom side), 22 nets.

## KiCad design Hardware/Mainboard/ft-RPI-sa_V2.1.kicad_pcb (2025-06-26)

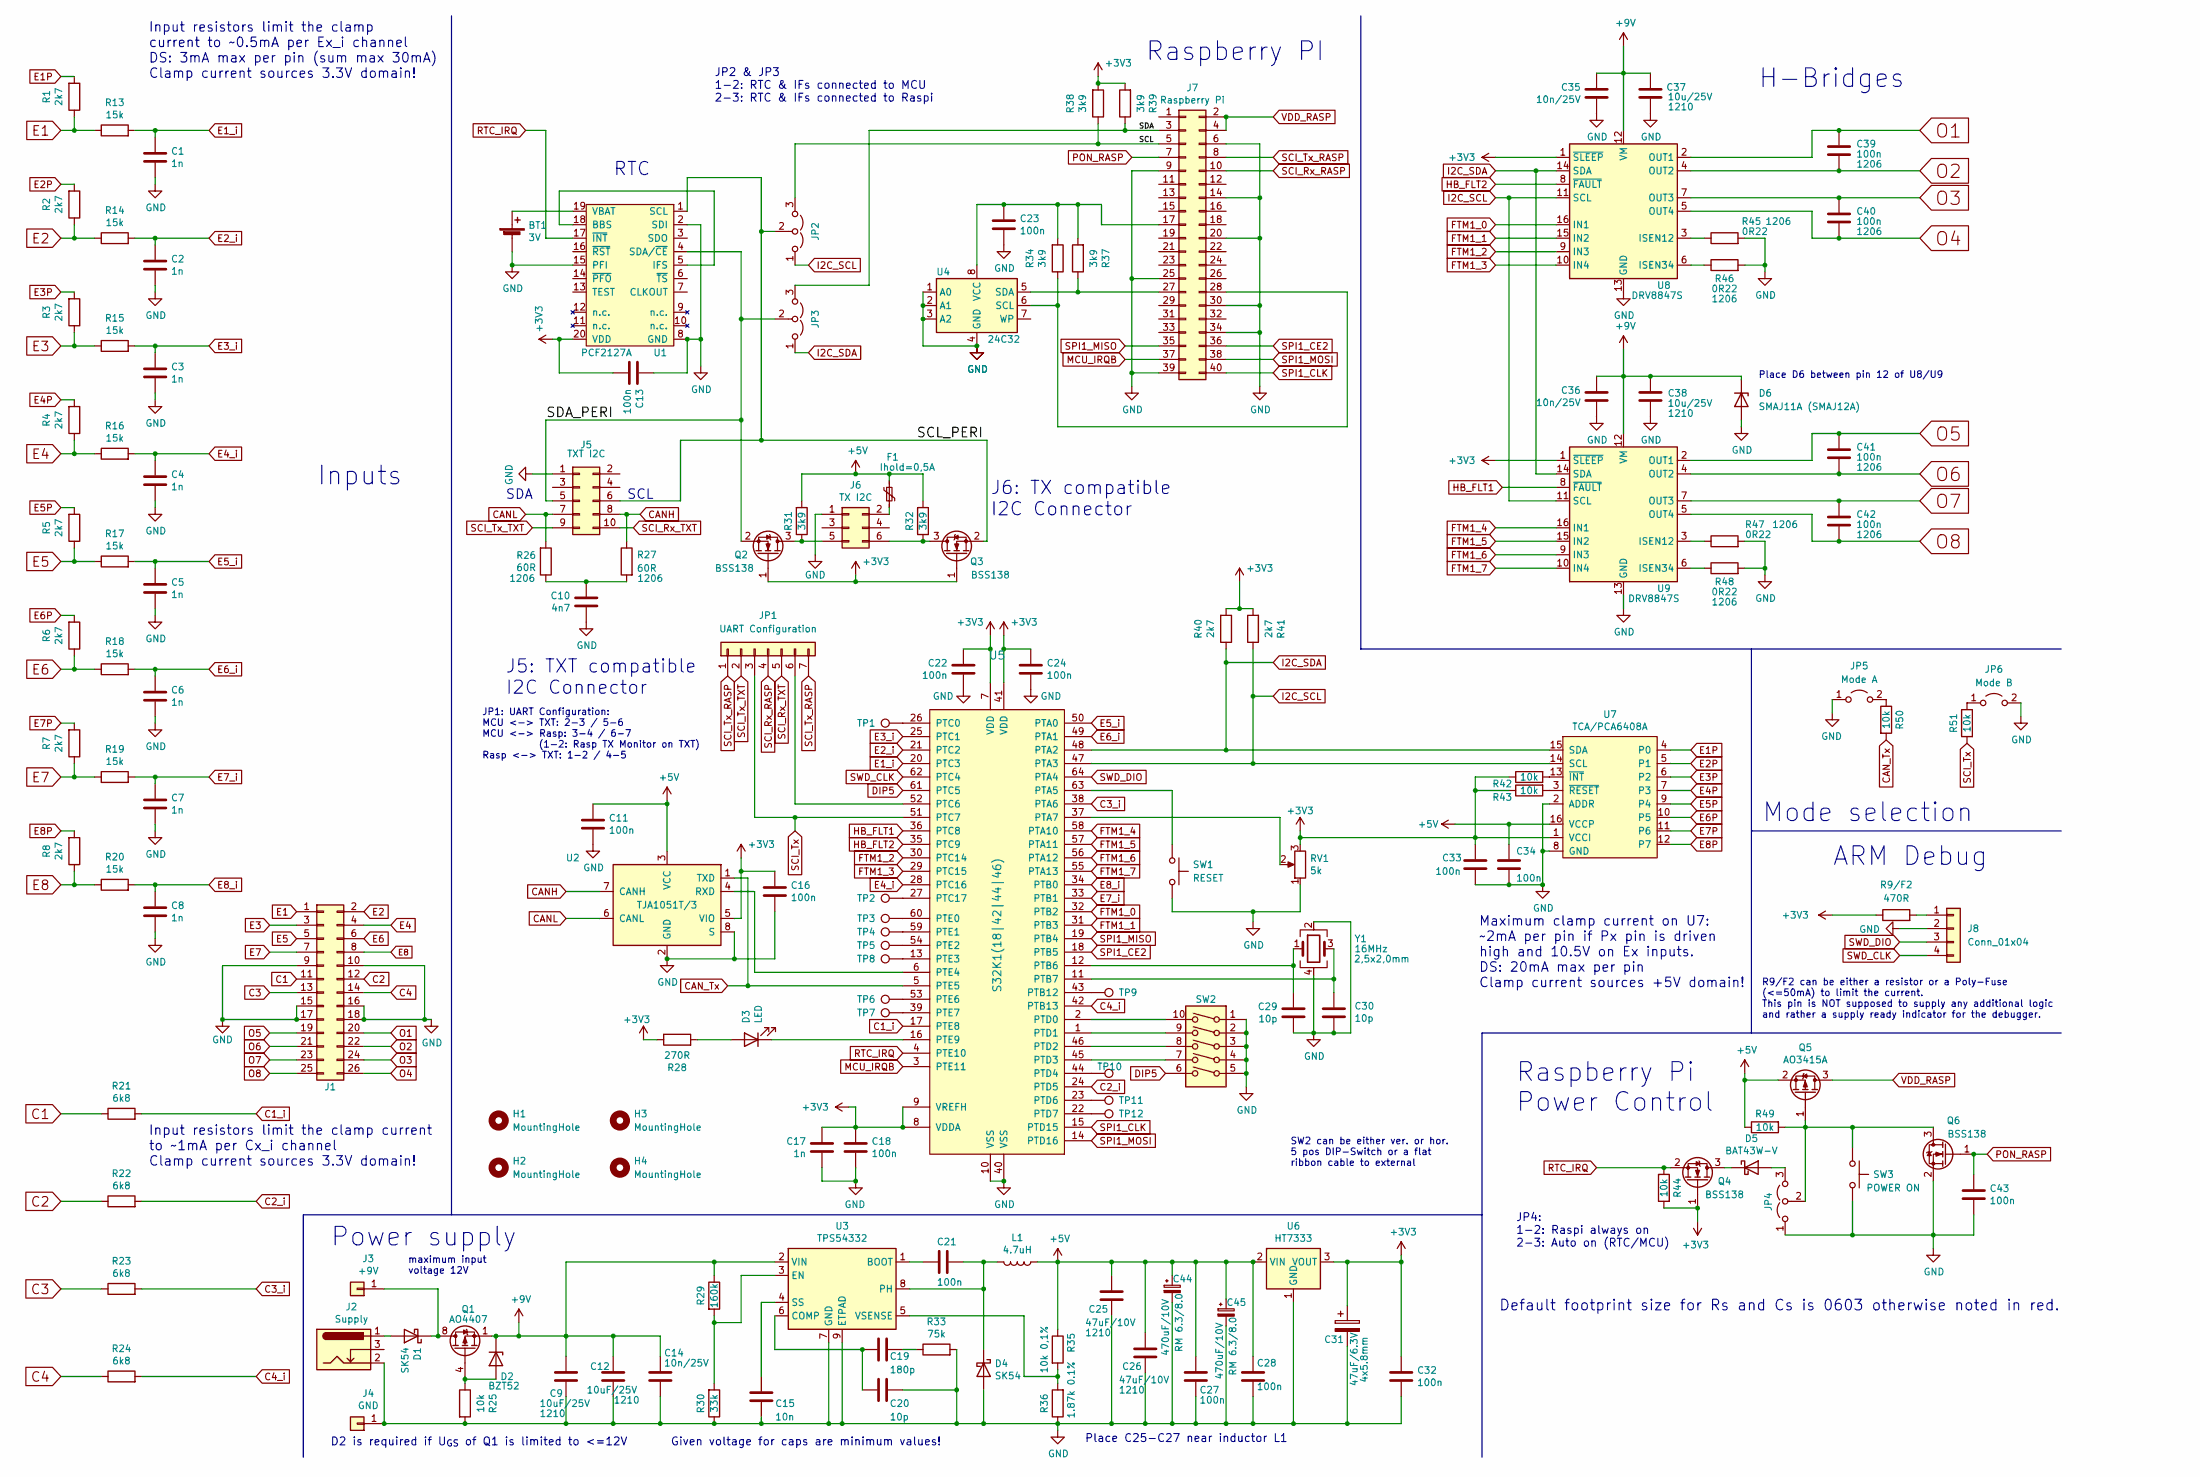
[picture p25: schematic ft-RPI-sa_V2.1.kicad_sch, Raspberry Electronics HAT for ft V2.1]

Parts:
BT1: 3V; BatteryHolder_Keystone_1058_1x2032
C1, C2, C3, C4, C5, C6, C7, C8, C17: 1n; C_0603_1608Metric_Pad1.08x0.95mm_HandSolder
C9, C12: 10uF/25V; C_1210_3225Metric_Pad1.33x2.70mm_HandSolder
C10: 4n7; C_0603_1608Metric_Pad1.08x0.95mm_HandSolder
C11, C13, C16, C18, C22, C23, C24, C27, C28, C32, C33, C34, C43: 100n; C_0603_1608Metric_Pad1.08x0.95mm_HandSolder
C14, C35, C36: 10n/25V; C_0603_1608Metric_Pad1.08x0.95mm_HandSolder
C15: 10n; C_0603_1608Metric_Pad1.08x0.95mm_HandSolder
C19: 180p; C_0603_1608Metric_Pad1.08x0.95mm_HandSolder
C20, C29, C30: 10p; C_0603_1608Metric_Pad1.08x0.95mm_HandSolder
C21: 100n; C_0603_1608Metric
C25, C26: 47uF/10V; C_1210_3225Metric_Pad1.33x2.70mm_HandSolder
C31: 47uF/6.3V; C_Elec_4x5.8
C37, C38: 10u/25V; C_1210_3225Metric_Pad1.33x2.70mm_HandSolder
C39, C40, C41, C42: 100n; C_1206_3216Metric_Pad1.33x1.80mm_HandSolder
C44, C45: 470uF/10V; CP_Elec_8x10
D1, D4: SK54; D_SMB
D2: BZT52; D_SOD-323
D3: LED; LED_D3.0mm
D5: BAT43W-V; D_SOD-123
D6: SMAJ11A (SMAJ12A); D_SMA
F1: Ihold=0,5A; R_1206_3216Metric_Pad1.30x1.75mm_HandSolder
H1: MountingHole; MountingHole_2.7mm_M2.5_ISO7380
H2, H3, H4: MountingHole; MountingHole_2.7mm_M2.5_DIN965
J1: Conn_02x13_Odd_Even; IDC-Header_2x13_P2.54mm_Horizontal
J2: Supply; BarrelJack_Horizontal
J3: +9V; 2.6mm Buchse
J4: GND; 2.6mm Buchse
J5: TXT I2C; IDC-Header_2x05_P2.54mm_Horizontal
J6: TX I2C; IDC-Header_2x03_P2.54mm_Horizontal
J7: Raspberry Pi; PinSocket_2x20_P2.54mm_Vertical
J8: Conn_01x04; PinHeader_1x04_P2.54mm_Vertical
JP1: UART Configuration; PinHeader_1x07_P2.00mm_Horizontal
JP2: I2C_SCL; PinHeader_1x03_P2.00mm_Horizontal
JP3: I2C_SDA; PinHeader_1x03_P2.00mm_Horizontal
JP4: RTC SDA; PinHeader_1x03_P2.00mm_Horizontal
JP5: Mode A; PinHeader_1x02_P2.00mm_Horizontal
JP6: Mode B; PinHeader_1x02_P2.00mm_Horizontal
L1: 4.7uH; Fastron_L-242418FPS
Q1: AO4407; SOIC-8_3.9x4.9mm_P1.27mm
Q2, Q3, Q4, Q6: BSS138; SOT-23
Q5: AO3415A; SOT-23
R1, R2, R3, R4, R5, R6, R7, R8, R40, R41: 2k7; R_0603_1608Metric_Pad0.98x0.95mm_HandSolder
R9/F2: 470R; R_0603_1608Metric_Pad0.98x0.95mm_HandSolder
R13, R14, R15, R16, R17, R18, R19, R20: 15k; R_0603_1608Metric_Pad0.98x0.95mm_HandSolder
R21, R22, R23, R24: 6k8; R_0603_1608Metric_Pad0.98x0.95mm_HandSolder
R25, R42, R43, R44, R49, R50, R51: 10k; R_0603_1608Metric_Pad0.98x0.95mm_HandSolder
R26, R27: 60R; R_1206_3216Metric_Pad1.30x1.75mm_HandSolder
R28: 270R; R_0603_1608Metric_Pad0.98x0.95mm_HandSolder
R29: 160k; R_0603_1608Metric_Pad0.98x0.95mm_HandSolder
R30: 33k; R_0603_1608Metric_Pad0.98x0.95mm_HandSolder
R31, R32, R34, R37, R38, R39: 3k9; R_0603_1608Metric_Pad0.98x0.95mm_HandSolder
R33: 75k; R_0603_1608Metric_Pad0.98x0.95mm_HandSolder
R35: 10k 0,1%; R_0603_1608Metric_Pad0.98x0.95mm_HandSolder
R36: 1.87k 0.1%; R_0603_1608Metric_Pad0.98x0.95mm_HandSolder
R45, R46, R47, R48: 0R22; R_1206_3216Metric_Pad1.30x1.75mm_HandSolder
RV1: 5k; Potentiometer_Piher_PT-10-H01_Horizontal
SW1: RESET; SW_Push_1P1T_NO_CK_KMR2
SW2: SW_DIP_x05; DIP-10_W7.62mm_LongPads_LPV
SW3: POWER ON; SW_Tactile_SPST_Angled_PTS645Vx83-2LFS
TP1, TP2, TP3, TP4, TP5, TP6, TP7, TP8, TP9, TP10, TP11, TP12: TestPoint; TestPoint_Pad_D0.8mm_open
U1: PCF2127A; SO-20_12.8x7.5mm_P1.27mm
U2: TJA1051T/3; SOIC-8_3.9x4.9mm_P1.27mm
U3: TPS54332; TI_SO-PowerPAD-8_ThermalVias
U4: 24C32; SOIC-8_3.9x4.9mm_P1.27mm
U5: S32K1(18|42|44|46); LQFP-64_10x10mm_P0.5mm
U6: HT7333; SOT-89-3
U7: TCA/PCA6408A; TSSOP-16_4.4x5mm_P0.65mm
U8, U9: DRV8847S; TSSOP-16_4.4x5mm_P0.65mm
Y1: 16MHz; Crystal_SMD_EuroQuartz_X22-4Pin_2.5x2.0mm

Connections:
+3V3: C13.1, C16.2, C17.2, C18.2, C22.2, C24.1, C31.1, C32.1, C33.1, Q2.1 (G), Q3.1 (G), Q4.1 (G), R9/F2.1, R28.1, R38.2, R39.2, R40.2, R41.2, R42.1, R43.1, R44.2, RV1.3, U1.20 (VDD), U2.5 (VIO), U5.7 (VDD), U5.8 (VDDA), U5.9 (VREFH), U5.41 (VDD), U6.3 (VOUT), U7.1 (VCCI), U8.1 (~SLEEP), U9.1 (~SLEEP)
+5V: C11.2, C25.1, C26.1, C27.1, C28.1, C34.1, C44.1, C45.1, F1.1, L1.1, Q5.2 (S), R31.2, R32.2, R35.1, R49.1, U2.3 (VCC), U6.2 (VIN), U7.16 (VCCP)
+9V: C9.1, C12.1, C14.1, C35.2, C36.2, C37.1, C38.1, D2.1 (K), D6.1 (K), Q1.1 (S), Q1.2 (S), Q1.3 (S), R29.1, U3.2 (VIN), U8.12 (VM), U9.12 (VM)
/SCL: J7.5, JP2.3 (B), R38.1
/SCL_PERI: J5.6, JP2.2 (C), Q3.2 (S), U1.1 (SCL)
/SDA: J7.3, JP3.3 (B), R39.1
/SDA_PERI: J5.5, JP3.2 (C), Q2.2 (S), U1.4 (SDA/~CE)
C1: J1.11, R21.1
C1_i: R21.2, U5.17 (PTE8)
C2: J1.12, R22.1
C2_i: R22.2, U5.24 (PTD5)
C3: J1.13, R23.1
C3_i: R23.2, U5.38 (PTA6)
C4: J1.14, R24.1
C4_i: R24.2, U5.42 (PTB13)
CANH: J5.8, R27.1, U2.7 (CANH)
CANL: J5.7, R26.2, U2.6 (CANL)
CAN_Tx: R50.2, U2.1 (TXD), U5.5 (PTE5)
DIP5: SW2.6, U5.61 (PTC5)
E1: J1.1, R1.1, R13.1
E1P: R1.2, U7.4 (P0)
E1_i: C1.1, R13.2, U5.20 (PTC3)
E2: J1.2, R2.1, R14.1
E2P: R2.2, U7.5 (P1)
E2_i: C2.1, R14.2, U5.21 (PTC2)
E3: J1.3, R3.1, R15.1
E3P: R3.2, U7.6 (P2)
E3_i: C3.1, R15.2, U5.25 (PTC1)
E4: J1.4, R4.1, R16.1
E4P: R4.2, U7.7 (P3)
E4_i: C4.1, R16.2, U5.28 (PTC16)
E5: J1.5, R5.1, R17.1
E5P: R5.2, U7.9 (P4)
E5_i: C5.1, R17.2, U5.50 (PTA0)
E6: J1.6, R6.1, R18.1
E6P: R6.2, U7.10 (P5)
E6_i: C6.1, R18.2, U5.49 (PTA1)
E7: J1.7, R7.1, R19.1
E7P: R7.2, U7.11 (P6)
E7_i: C7.1, R19.2, U5.33 (PTB1)
E8: J1.8, R8.1, R20.1
E8P: R8.2, U7.12 (P7)
E8_i: C8.1, R20.2, U5.34 (PTB0)
FTM1_0: U5.32 (PTB2), U8.16 (IN1)
FTM1_1: U5.31 (PTB3), U8.15 (IN2)
FTM1_2: U5.30 (PTC14), U8.9 (IN3)
FTM1_3: U5.29 (PTC15), U8.10 (IN4)
FTM1_4: U5.58 (PTA10), U9.16 (IN1)
FTM1_5: U5.57 (PTA11), U9.15 (IN2)
FTM1_6: U5.56 (PTA12), U9.9 (IN3)
FTM1_7: U5.55 (PTA13), U9.10 (IN4)
GND: BT1.2 (-), C1.2, C2.2, C3.2, C4.2, C5.2, C6.2, C7.2, C8.2, C9.2, C10.1, C11.1, C12.2, C13.2, C14.2, C15.2, C16.1, C17.1, C18.1, C20.1, C22.1, C23.1, C24.2, C25.2, C26.2, C27.2, C28.2, C29.1, C30.1, C31.2, C32.2, C33.2, C34.2, C35.1, C36.1, C37.2, C38.2, C43.2, C44.2, C45.2, D4.2 (A), D6.2 (A), J1.9, J1.10, J1.15, J1.16, J1.17, J1.18, J2.2, J4.1, J5.1, J6.1, J7.6, J7.9, J7.14, J7.20, J7.25, J7.30, J7.34, J7.39, J8.2, JP4.1 (A), JP5.1 (A), JP6.2 (B), Q6.2 (S), R25.2, R30.1, R33.2, R36.1, R45.2, R46.2, R47.2, R48.2, RV1.1, SW1.2, SW2.1, SW2.2, SW2.3, SW2.4, SW2.5, SW3.2, U1.2 (SDI), U1.8 (GND), U1.15 (PFI), U2.2 (GND), U2.8 (S), U3.7 (GND), U3.9 (ETPAD), U4.1 (A0), U4.2 (A1), U4.3 (A2), U4.4 (GND), U5.10 (VSS), U5.40 (VSS), U6.1 (GND), U7.2 (ADDR), U7.8 (GND), U8.13 (GND), U9.13 (GND), Y1.2, Y1.4
HB_FLT1: U5.36 (PTC8), U9.8 (~FAULT)
HB_FLT2: U5.35 (PTC9), U8.8 (~FAULT)
I2C_SCL: JP2.1 (A), R41.1, U5.47 (PTA3), U7.14 (SCL), U8.11 (SCL), U9.11 (SCL)
I2C_SDA: JP3.1 (A), R40.1, U5.48 (PTA2), U7.15 (SDA), U8.14 (SDA), U9.14 (SDA)
MCU_IRQB: J7.37, U5.3 (PTE11)
unnamed: BT1.1 (+), U1.19 (VBAT)
unnamed: C10.2, R26.1, R27.2
unnamed: C19.1, R33.1
unnamed: D1.2 (A), J2.1
unnamed: D1.1 (K), J3.1, Q1.5 (D), Q1.6 (D), Q1.7 (D), Q1.8 (D)
unnamed: D2.2 (A), Q1.4 (G), R25.1
unnamed: D3.2 (A), R28.2
unnamed: D3.1 (K), U5.16 (PTE9)
unnamed: C21.1, D4.1 (K), L1.2, U3.8 (PH)
unnamed: D5.2 (A), JP4.3 (B)
unnamed: D5.1 (K), Q4.3 (D)
unnamed: F1.2, J6.2
unnamed: J6.5, Q2.3 (D), R31.1
unnamed: J6.6, Q3.3 (D), R32.1
unnamed: C23.2, J7.17, R34.2, R37.2, U4.8 (VCC)
unnamed: J7.27, R37.1, U4.5 (SDA)
unnamed: J7.28, R34.1, U4.6 (SCL)
unnamed: J8.1, R9/F2.2
unnamed: JP1.6, U5.52 (PTC6)
unnamed: JP4.2 (C), Q5.1 (G), Q6.3 (D), R49.2, SW3.1
unnamed: JP5.2 (B), R50.1
unnamed: JP6.1 (A), R51.1
unnamed: U1.5 (IFS), U1.18 (BBS)
unnamed: U2.4 (RXD), U5.6 (PTE4)
unnamed: C21.2, U3.1 (BOOT)
unnamed: C19.2, C20.2, U3.6 (COMP)
unnamed: R29.2, R30.2, U3.3 (EN)
unnamed: C15.1, U3.4 (SS)
unnamed: R35.2, R36.2, U3.5 (VSENSE)
unnamed: SW1.1, U5.63 (PTA5)
unnamed: RV1.2, U5.37 (PTA7)
unnamed: C29.2, U5.12 (PTB6), Y1.1
unnamed: C30.2, U5.11 (PTB7), Y1.3
unnamed: TP9.1, U5.43 (PTB12)
unnamed: TP1.1, U5.26 (PTC0)
unnamed: TP2.1, U5.27 (PTC17)
unnamed: SW2.10, U5.2 (PTD0)
unnamed: SW2.9, U5.1 (PTD1)
unnamed: SW2.8, U5.46 (PTD2)
unnamed: SW2.7, U5.45 (PTD3)
unnamed: TP10.1, U5.44 (PTD4)
unnamed: TP11.1, U5.23 (PTD6)
unnamed: TP12.1, U5.22 (PTD7)
unnamed: TP3.1, U5.60 (PTE0)
unnamed: TP4.1, U5.59 (PTE1)
unnamed: TP5.1, U5.54 (PTE2)
unnamed: TP8.1, U5.13 (PTE3)
unnamed: TP6.1, U5.53 (PTE6)
unnamed: TP7.1, U5.39 (PTE7)
unnamed: R42.2, U7.13 (~INT)
unnamed: R43.2, U7.3 (~RESET)
unnamed: R45.1, U8.3 (ISEN12)
unnamed: R46.1, U8.6 (ISEN34)
unnamed: R47.1, U9.3 (ISEN12)
unnamed: R48.1, U9.6 (ISEN34)
O1: C39.1, J1.20, U8.2 (OUT1)
O2: C39.2, J1.22, U8.4 (OUT2)
O3: C40.1, J1.24, U8.7 (OUT3)
O4: C40.2, J1.26, U8.5 (OUT4)
O5: C41.1, J1.19, U9.2 (OUT1)
O6: C41.2, J1.21, U9.4 (OUT2)
O7: C42.1, J1.23, U9.7 (OUT3)
O8: C42.2, J1.25, U9.5 (OUT4)
PON_RASP: C43.1, J7.7, Q6.1 (G)
RTC_IRQ: Q4.2 (S), R44.1, U1.17 (~INT), U5.4 (PTE10)
SCI_Rx_RASP: J7.10, JP1.4
SCI_Rx_TXT: J5.10, JP1.5
SCI_Tx: JP1.3, R51.2, U5.51 (PTC7)
SCI_Tx_RASP: J7.8, JP1.1, JP1.7
SCI_Tx_TXT: J5.9, JP1.2
SPI1_CE2: J7.36, U5.18 (PTB5)
SPI1_CLK: J7.40, U5.15 (PTD15)
SPI1_MISO: J7.35, U5.19 (PTB4)
SPI1_MOSI: J7.38, U5.14 (PTD16)
SWD_CLK: J8.4, U5.62 (PTC4)
SWD_DIO: J8.3, U5.64 (PTA4)
VDD_RASP: J7.2, J7.4, Q5.3 (D)

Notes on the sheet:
Place C25-C27 near inductor L1
Raspberry PI
Default footprint size for Rs and Cs is 0603 otherwise noted in red.
J6: TX compatible I2C Connector
D2 is required if U_{GS} of Q1 is limited to <=12V
Mode selection
Input resistors limit the clamp current to ~0.5mA per Ex_i channel DS: 3mA max per pin (sum max 30mA) Clamp current sources 3.3V domain!
SCL
Maximum clamp current on U7: ~2mA per pin if Px pin is driven high and 10.5V on Ex inputs. DS: 20mA max per pin Clamp current sources +5V domain!
H-Bridges
Inputs
Power supply
JP2 & JP3 1-2: RTC & IFs connected to MCU 2-3: RTC & IFs connected to Raspi
maximum input voltage 12V
SDA
Raspberry Pi Power Control
SW2 can be either ver. or hor. 5 pos DIP-Switch or a flat ribbon cable to external
J5: TXT compatible I2C Connector
ARM Debug
R9/F2 can be either a resistor or a Poly-Fuse (<=50mA) to limit the current. This pin is NOT supposed to supply any additional logic and rather a supply ready indicator for the debugger.
Place D6 between pin 12 of U8/U9
JP4: 1-2: Raspi always on 2-3: Auto on (RTC/MCU)
JP1: UART Configuration: MCU <-> TXT: 2-3 / 5-6 MCU <-> Rasp: 3-4 / 6-7 (1-2: Rasp TX Monitor on TXT) Rasp <-> TXT: 1-2 / 4-5
Given voltage for caps are minimum values!
Input resistors limit the clamp current to ~1mA per Cx_i channel Clamp current sources 3.3V domain!
RTC

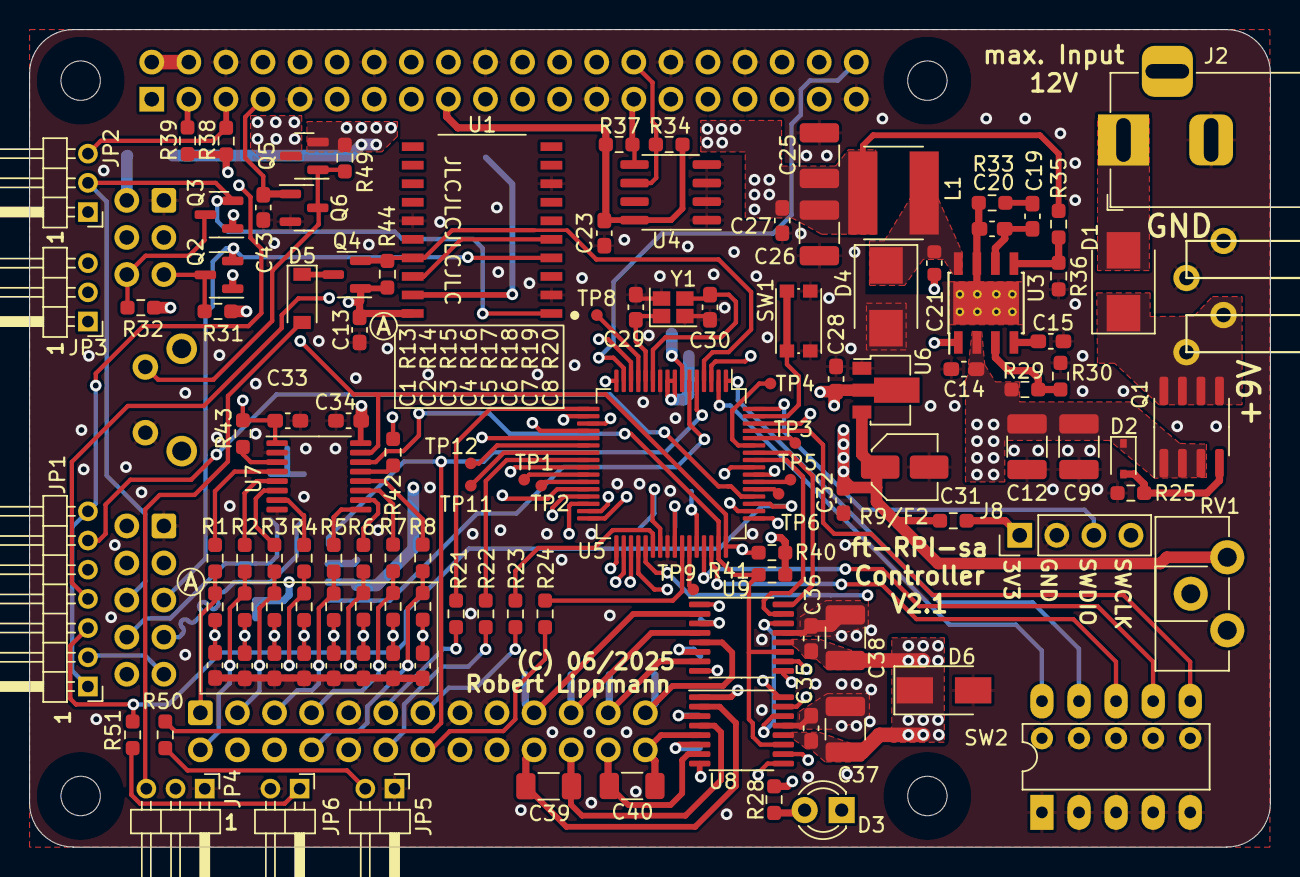
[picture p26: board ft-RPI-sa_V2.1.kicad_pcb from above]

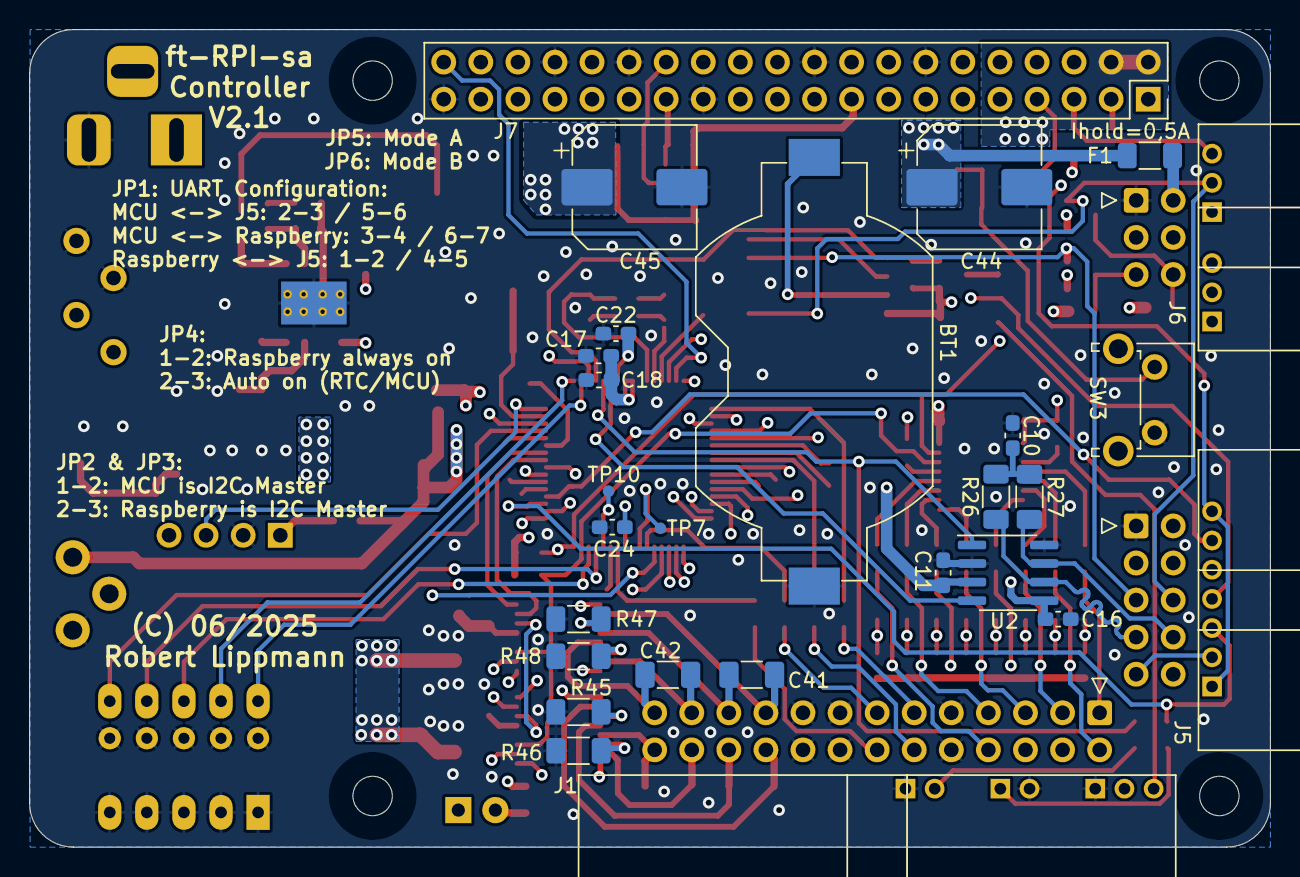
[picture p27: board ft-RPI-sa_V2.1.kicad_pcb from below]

Board: 4 copper layers, 85.0 x 56.0 mm, 152 parts (27 on the bottom side), 134 nets.

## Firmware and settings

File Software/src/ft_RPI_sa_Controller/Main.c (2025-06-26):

/*****************************************************************************************************************************
fischertechnik-Raspberry Pi-Stand-Alone Controller

Main.c

Copyright 2011 - 2021 Geoff Graham.  All Rights Reserved.
Adaption to S32K1 family and the ft-RPI-sa hardware: Copyright 2022 Robert Lippmann

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
1. Redistributions of source code must retain the above copyright notice,
   this list of conditions and the following disclaimer.

2. Redistributions in binary form must reproduce the above copyright notice,
   this list of conditions and the following disclaimer in the documentation
   and/or other materials provided with the distribution.

3. Neither the name of the copyright holders nor the names of its contributors
   may be used to endorse or promote products derived from this software
   without specific prior written permission.

4. The name MMBasic be used when referring to the interpreter in any
   documentation and promotional material and the original copyright message
   be displayed  on the console at startup (additional copyright messages may
   be added).

5. All advertising materials mentioning features or use of this software must
   display the following acknowledgement: This product includes software
   developed by Geoff Graham and Peter Mather.

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

This is the main source file for the ft-RPA-sa project.

Development Environment
    To compile this you need:
     - S32 Design Studio 3.5 with S32K1 family support package

********************************************************************************/

#define DEFINE_PINDEF_TABLE                                         // this will create the PinDef tables defined in IOPorts.h
#include "Version.h"

// global variables used in MMBasic but must be maintained outside of the interpreter
int MMCharPos;
volatile int MMAbort = false;
//char *InterruptReturn = NULL;

char BreakKey = BREAK_KEY;                                          // defaults to CTRL-C.  Set to zero to disable the break function
char IgnorePIN = false;
char WatchdogSet = false;


unsigned int __attribute__((section(".NoInit"))) _excep_MagicNumber;
unsigned int __attribute__((section(".NoInit"))) _excep_code;
unsigned int __attribute__((section(".NoInit"))) _excep_addr;
unsigned int __attribute__((section(".NoInit"))) _excep_cause;

int main(int argc, char* argv[]) {
    int i;
    static int ErrorInPrompt;

    InitProcessor();                                                // do the setup stuff specific to the particular chip

    if((IP_RCM->SSRS & RCM_SSRS_SPOR_MASK) || (_excep_MagicNumber != 0x27fe0811)) // check whether device is starting up first time
    {
    	IP_RCM->SSRS = RCM_SSRS_SPOR_MASK;				// clear POR sticky bit
        // Need to initialize ECC before using these RAM addresses
    	_excep_code = 0;							// clear/init all variables and save MagicNumber
    	_excep_cause = 0;							// to avoid initialization next time
    	_excep_addr = 0;
    	_excep_MagicNumber = 0x27fe0811;
    }

    InitBasic();
    ErrorInPrompt = false;

    WatchdogSet = false;
    if(_excep_code != 0) {                                             // this will only happen if we had a software triggered reset
        if(!(_excep_code == RESTART_NOAUTORUN || _excep_code == RESTART_DOAUTORUN)) {
            if(_excep_code == WATCHDOG_TIMEOUT) {
                WatchdogSet = true;                                 // remember if it was a watchdog timeout
                MMPrintString("\r\n\nWatchdog timeout");
            } else if(_excep_code == RESET_COMMAND) {
            	MMPrintString("\r\n\nRESET command");
            } else if(_excep_code != PIN_RESTART) {
                if(_excep_cause != CAUSE_NOTHING) {
                    if(_excep_cause == CAUSE_MMSTARTUP)
                        MMPrintString("\r\n\nError in MM.STARTUP");
                } else {
                    MMPrintString("\r\n\nCPU exception #");
                    IntToStrPad(inpbuf, _excep_code, '0', 1, 10); MMPrintString(inpbuf);
                    PrepareProgram(false);
                    if(CFunctionFlash != NULL && _excep_addr >= (unsigned int)CFunctionFlash && _excep_addr < (unsigned int)ProgMemory + PROG_FLASH_SIZE) {
                        unsigned int *wrd;
                        char *p;
                        MMPrintString("\r\nIn CFunction ");
                        wrd = (unsigned int *)CFunctionFlash;
                        while(*wrd != 0xffffffff) {
                            if(_excep_addr <= (unsigned int)wrd + wrd[1] + 4) {
                                _excep_addr -= ((unsigned int)wrd + 12);
                                p = (char *)wrd[0];
                                p++; skipspace(p);
                                MMputchar(*p++);
                                while(isnamechar((int)*p)) MMputchar(*p++);
                                break;
                            }
                            wrd++;
                            wrd += (*wrd + 4) / sizeof(unsigned int);
                        }
                    }
                    MMPrintString(" at address 0x");
                    IntToStrPad(inpbuf, _excep_addr, '0', 4, 16); MMPrintString(inpbuf);
                }
            }
            MMPrintString("\r\nProcessor restarted\r\n\n");
            uSec(200000);
        }
    }
    else {
#if defined(DEBUGMODE) || defined(__DEBUG)
        dp("Debug mode.  %d command and %d token slots free.", 127 - CommandTableSize, 127 - TokenTableSize);
#else
        MMPrintString(MES_SIGNON);                                  // print sign on message
        MMPrintString(COPYRIGHT);                                   // print copyright message
        MMPrintString("\r\n");
#endif
    }

    if(setjmp(mark) != 0) {
        // we got here via a long jump which means an error or CTRL-C or the program wants to exit to the command prompt
    	AllOutputsOff();											// First, switch all outputs off once CTRL-C is pressed
        ContinuePoint = nextstmt;                                   // in case the user wants to use the continue command
        *tknbuf = 0;                                                // we do not want to run whatever is in the token buffer
    } else {
        if(_excep_cause != CAUSE_MMSTARTUP) {
            ClearProgram();
            PrepareProgram(true);
            _excep_cause = CAUSE_MMSTARTUP;
#if defined(TEST_CONFIG)
            CurrentLinePtr = inpbuf;
            strcpy(inpbuf, TEST_CONFIG);
            tokenise(true);
            ExecuteProgram(tknbuf);
#endif
            if(FindSubFun("MM.STARTUP", 0) >= 0) ExecuteProgram("MM.STARTUP\0");
            _excep_cause = CAUSE_NOTHING;
            if((Option.Autorun || _excep_code == RESTART_DOAUTORUN) && *ProgMemory == 0x01 && _excep_code != RESTART_NOAUTORUN) {
                CurrentLinePtr = NULL;                                      // do not use the line number in error reporting
                //if(Option.ProgFlashSize != PROG_FLASH_SIZE) ExecuteProgram(ProgMemory + Option.ProgFlashSize);       // run anything that might be in the library
                ExecuteProgram(ProgMemory);                                                                          // then run the program if autorun is on
            }
        }
    }
    _excep_cause = CAUSE_NOTHING;

    while(1) {
        MMAbort = false;
        BreakKey = BREAK_KEY;
        EchoOption = true;
        LocalIndex = 0;                                             // this should not be needed but it ensures that all space will be cleared
        ClearTempMemory();                                          // clear temp string space (might have been used by the prompt)
        CurrentLinePtr = NULL;                                      // do not use the line number in error reporting
        if(MMCharPos > 1) MMPrintString("\r\n");                    // prompt should be on a new line
        while(Option.PIN && !IgnorePIN) {
            _excep_code = PIN_RESTART;
            if(Option.PIN == 99999999)                              // 99999999 is permanent lockdown
                MMPrintString("Console locked, press enter to restart: ");
            else
                MMPrintString("Enter PIN or 0 to restart: ");
            MMgetline(0, inpbuf);
            if(Option.PIN == 99999999) SystemSoftwareReset();
            if(*inpbuf != 0) {
            	for(i=0;i<30;i++)
            	{
            		uSec(100000);	// wait for 100ms (3s in total)
            	}
                i = atoi(inpbuf);
                if(i == 0) SystemSoftwareReset();
                if(i == Option.PIN) {
                    IgnorePIN = true;
                    break;
                }
            }
        }
        _excep_code = 0;
        PrepareProgram(false);
        CurrentLinePtr = NULL;                  // PrepareProgram changes this ptr but with that, some commands
        										// are not usable even on cli (e.g. edit) -> therefore I need to clear this here (added by RLI)
        if(!ErrorInPrompt && FindSubFun("MM.PROMPT", 0) >= 0) {
            ErrorInPrompt = true;
            ExecuteProgram("MM.PROMPT\0");
        } else
            MMPrintString("> ");                                    // print the prompt
        ErrorInPrompt = false;
        MMgetline(0, inpbuf);                                       // get the input
        if(!*inpbuf) continue;                                      // ignore an empty line
        tokenise(true);                                             // turn into executable code
        ExecuteProgram(tknbuf);                                     // execute the line straight away
    }
}

/********************************************************************************************************************************************
 Program memory management
*********************************************************************************************************************************************/

// takes a pointer to RAM containing a program (in clear text) and writes it to program flash in tokenised format
void SaveProgramToFlash(char *pm, int msg) {
    char *p, prevchar = 0, buf[STRINGSIZE];
    int nbr;

    memcpy(buf, tknbuf, STRINGSIZE);                                // save the token buffer because we are going to use it
    IP_LMEM->PCCCR = LMEM_PCCCR_INVW0(1) | LMEM_PCCCR_INVW1(1) | LMEM_PCCCR_GO(1) | LMEM_PCCCR_ENCACHE(0); // disable cache

    FlashWriteInit(ProgMemory, 0);                                  // Initialize for flash write but do not erase any pages

    nbr = 0;                                                        // this is used to count the number of bytes written to flash
    while(*pm) {
        p = inpbuf;
        while(!(*pm == 0 || *pm == '\r' || (*pm == '\n' && prevchar != '\r'))) {
            if(*pm == TAB) {
                do {*p++ = ' ';
                    if((p - inpbuf) >= MAXSTRLEN) goto exiterror2;
                } while((p - inpbuf) % 2);
            } else {
                if(isprint((int)*pm)) {
                    *p++ = *pm;
                    if((p - inpbuf) >= MAXSTRLEN) goto exiterror2;
                }
            }
            prevchar = *pm++;
        }
        if(*pm) prevchar = *pm++;                                   // step over the end of line char but not the terminating zero
        *p = 0;                                                     // terminate the string in inpbuf

        if(*inpbuf == 0 && (*pm == 0 || (!isprint((int)*pm) && pm[1] == 0))) break; // don't save a trailing newline

        tokenise(false);                                            // turn into executable code
        p = tknbuf;
        while(!(p[0] == 0 && p[1] == 0)) {
            FlashWriteByteErase(*p++); nbr++;

            if((int)(flashptr - ProgMemory) >= Option.ProgFlashSize - 9)
                goto exiterror1;
        }
        FlashWriteByteErase(0); nbr++;                              // terminate that line in flash
    }
    while(flashptr<(ProgMemory+12)) FlashWriteByteErase(0);
    FlashWriteByteErase(0); FlashWriteByteErase(0);                 // terminate the program in flash
    FlashWriteByteErase(0xff);                                      // this is for routines that scan the flash and expected the program area to be terminated with 0xff
    FlashWriteClose();
    IP_LMEM->PCCCR = LMEM_PCCCR_INVW0(1) | LMEM_PCCCR_INVW1(1) | LMEM_PCCCR_GO(1) | LMEM_PCCCR_ENCACHE(1); // re-enable cache

    if(msg) {                                                       // if requested by the caller, print an informative message
        if(MMCharPos > 1) MMPrintString("\r\n");                    // message should be on a new line
        MMPrintString("Saved ");
        IntToStr(tknbuf, nbr + 3, 10);
        MMPrintString(tknbuf);
        MMPrintString(" bytes\r\n");
    }
    memcpy(tknbuf, buf, STRINGSIZE);                                // restore the token buffer in case there are other commands in it
    return;

    // we only get here if we have run out of memory
    exiterror1:
        FlashWriteByteErase(0); FlashWriteByteErase(0); FlashWriteByteErase(0);    // terminate the program in flash
        FlashWriteClose();
        IP_LMEM->PCCCR = LMEM_PCCCR_INVW0(1) | LMEM_PCCCR_INVW1(1) | LMEM_PCCCR_GO(1) | LMEM_PCCCR_ENCACHE(1); // re-enable cache
        error("Not enough memory");

    // we only get here if a line was too long
    exiterror2:
        FlashWriteByteErase(0); FlashWriteByteErase(0); FlashWriteByteErase(0);    // terminate the program in flash
        FlashWriteClose();
        IP_LMEM->PCCCR = LMEM_PCCCR_INVW0(1) | LMEM_PCCCR_INVW1(1) | LMEM_PCCCR_GO(1) | LMEM_PCCCR_ENCACHE(1); // re-enable cache
        error("Line is too long");
}




// put a character out to the serial console
char MMputchar(char c) {
    putConsole(c);
    if(isprint(c)) MMCharPos++;
    if(c == '\r') {
        MMCharPos = 1;
    }
    return c;
}



/*****************************************************************************************
The vt100 escape code sequences
===============================
3 char codes            Arrow Up    esc [ A
                        Arrow Down  esc [ B
                        Arrow Right esc [ C
                        Arrow Left  esc [ D

4 char codes            Home        esc [ 1 ~
                        Insert      esc [ 2 ~
                        Del         esc [ 3 ~
                        End         esc [ 4 ~
                        Page Up     esc [ 5 ~
                        Page Down   esc [ 6 ~

5 char codes            F1          esc [ 1 1 ~
                        F2          esc [ 1 2 ~
                        F3          esc [ 1 3 ~
                        F4          esc [ 1 4 ~
                        F5          esc [ 1 5 ~         note the
                        F6          esc [ 1 7 ~         disconnect
                        F7          esc [ 1 8 ~
                        F8          esc [ 1 9 ~
                        F9          esc [ 2 0 ~
                        F10         esc [ 2 1 ~         note the
                        F11         esc [ 2 3 ~         disconnect
                        F12         esc [ 2 4 ~

                        SHIFT-F3    esc [ 2 5 ~         used in the editor

 Linux terminal emulators use the older escape codes for F1-F4 (was PF1-PF4 on the original VT100).
 These use <esc>OP through to <esc>OS rather than the [ sequence.
 
*****************************************************************************************/

// check if there is a keystroke waiting in the buffer and, if so, return with the char
// returns -1 if no char waiting
// the main work is to check for vt100 escape code sequences and map to Maximite codes
int MMInkey(void) {
    unsigned int c = -1;                                            // default no character
    unsigned int tc = -1;                                           // default no character
    unsigned int ttc = -1;                                          // default no character
    static unsigned int c1 = -1;
    static unsigned int c2 = -1;
    static unsigned int c3 = -1;
    static unsigned int c4 = -1;

    if(c1 != -1) {                                                  // check if there are discarded chars from a previous sequence
        c = c1; c1 = c2; c2 = c3; c3 = c4; c4 = -1;                 // shuffle the queue down
        return c;                                                   // and return the head of the queue
    }

    c = getConsole();                                               // do discarded chars so get the char
    if(c == 0x1b) {
        InkeyTimer = 0;                                             // start the timer
        while((c = getConsole()) == -1 && InkeyTimer < 30);         // get the second char with a delay of 30mS to allow the next char to arrive
        if(c == 'O') {                                              // support for many Linux terminal emulators (Peter Mather)
            while((c = getConsole()) == -1 && InkeyTimer < 50);     // delay some more to allow the final chars to arrive, even at 1200 baud
            if(c == 'P') return F1;
            if(c == 'Q') return F2;
            if(c == 'R') return F3;
            if(c == 'S') return F4;
            if(c == 'F') return END;								// minicom in VT102 mode
            if(c == 'P') {
                while((tc = getConsole()) == -1 && InkeyTimer < 70);// more delay for more chars to arrive
                if(tc == 'R') return F3 + 0x20;
                c1 = 'O'; c2 = c; c3 = tc; return 0x1b;             // not a valid 4 char code
            }
            c1 = 'O'; c2 = c; return 0x1b;                          // not a valid code
        }
        if(c != '[') { c1 = c; return 0x1b; }                       // must be a square bracket
        while((c = getConsole()) == -1 && InkeyTimer < 50);         // get the third char with delay
        if(c == 'A') return UP;                                     // the arrow keys are three chars
        if(c == 'B') return DOWN;
        if(c == 'C') return RIGHT;
        if(c == 'D') return LEFT;
        if(c < '1' && c > '6') { c1 = '['; c2 = c; return 0x1b; }   // the 3rd char must be in this range
        while((tc = getConsole()) == -1 && InkeyTimer < 70);        // delay some more to allow the final chars to arrive, even at 1200 baud
        if(tc == '~') {                                             // all 4 char codes must be terminated with ~
            if(c == '1') return HOME;
            if(c == '2') return INSERT;
            if(c == '3') return DEL;
//            if(c == '4') return END;
            if(c == '5') return PUP;
            if(c == '6') return PDOWN;
            c1 = '['; c2 = c; c3 = tc; return 0x1b;                 // not a valid 4 char code
        }
        while((ttc = getConsole()) == -1 && InkeyTimer < 90);       // get the 5th char with delay
        if(ttc == '~') {                                            // must be a ~
            if(c == '1') {
                if(tc >='1' && tc <= '4') return F1 + (tc - '1');   // F1 to F4 (was 5 instead of 4)
                if(tc >='6' && tc <= '9') return F5 + (tc - '6');   // F5 to F8 (was 7 instead of 6 and F6 instead of F5!)
            }
            if(c == '2') {
                if(tc =='0' || tc == '1') return F9 + (tc - '0');   // F9 and F10
                if(tc =='3' || tc == '4') return F11 + (tc - '3');  // F11 and F12
                if(tc =='5') return F3 + 0x20;                      // SHIFT-F3
            }
        }
        // nothing worked so bomb out
        c1 = '['; c2 = c; c3 = tc; c4 = ttc;
        return 0x1b;
    }
    return c;
}

void DefaultISR(void) {
    _excep_code = (_excep_code & 0x0000007C) >> 2;

    SystemSoftwareReset();        // this will restart the processor
}

#if defined(DEBUGMODE)
// dump a memory area to the console
// for debugging
void dump(char *p, int nbr) {
    char buf1[80], buf2[80], *b1, *b2, *pt;
    b1 = buf1; b2 = buf2;
    MMPrintString("   addr    0  1  2  3  4  5  6  7  8  9  A  B  C  D  E  F    0123456789ABCDEF\r\n");
    b1 += sprintf(b1, "%8x: ", (unsigned int)p);
    for(pt = p; (unsigned int)pt % 16 != 0; pt--) {
        b1 += sprintf(b1, "   ");
        b2 += sprintf(b2, " ");
    }
    while(nbr > 0) {
        b1 += sprintf(b1, "%02x ", *p);
        b2 += sprintf(b2, "%c", (*p >= ' ' && *p < 0x7f) ? *p : '.');
        p++;
        nbr--;
        if((unsigned int)p % 16 == 0) {
            MMPrintString(buf1);
            MMPrintString("   ");
            MMPrintString(buf2);
            b1 = buf1; b2 = buf2;
            b1 += sprintf(b1, "\r\n%8x: ", (unsigned int)p);
        }
    }
    if(b2 != buf2) {
        MMPrintString(buf1);
        MMPrintString("   ");
        for(pt = p; (unsigned int)pt % 16 != 0; pt++) {
            MMPrintString("   ");
        }
      MMPrintString(buf2);
    }
    MMPrintString("\r\n");
}
#endif

// a crude memory dump that does not use sprintf()
void cdump(char *p, int nbr) {
    while(nbr--) {
        if(((int)p & 0b11111) == 0) MMPrintString("\r\n");
        if(*p == 0)
            MMPrintString("= ");
        else if(*p == T_NEWLINE)
            MMPrintString("@ ");
        else if(*p == T_LINENBR)
            MMPrintString("% ");
        else if(isprint((int)*p))
            { MMputchar(*p); MMputchar(' '); }
        else MMPrintString(". ");
        p++;
    }
    MMPrintString("\r\n");
}

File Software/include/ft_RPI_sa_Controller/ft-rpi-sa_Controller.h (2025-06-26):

/************************************************************************************************************************
fischertechnik-Raspberry Pi-Stand-Alone Controller

ft-rpi-sa_Controller.h

Contains all the required board specific defines of the ft-RPI-sa Controller

Copyright 2022 Robert Lippmann

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
1. Redistributions of source code must retain the above copyright notice,
   this list of conditions and the following disclaimer.

2. Redistributions in binary form must reproduce the above copyright notice,
   this list of conditions and the following disclaimer in the documentation
   and/or other materials provided with the distribution.

3. Neither the name of the copyright holders nor the names of its contributors
   may be used to endorse or promote products derived from this software
   without specific prior written permission.

4. The name MMBasic be used when referring to the interpreter in any
   documentation and promotional material and the original copyright message
   be displayed  on the console at startup (additional copyright messages may
   be added).

5. All advertising materials mentioning features or use of this software must
   display the following acknowledgement: This product includes software
   developed by Robert Lippmann.

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
*******************************************************************************/

#ifndef FT_RPI_SA_CONTROLLER_FT_RPI_SA_CONTROLLER_H_
#define FT_RPI_SA_CONTROLLER_FT_RPI_SA_CONTROLLER_H_

enum {
	PTA0=0,
	PTA1,
	PTA2,
	PTA3,
	PTA4,
	PTA5,
	PTA6,
	PTA7,
	PTA8_NC,
	PTA9_NC,
	PTA10,
	PTA11,
	PTA12,
	PTA13
};

enum {
	PTB0=0,
	PTB1,
	PTB2,
	PTB3,
	PTB4,
	PTB5,
	PTB6,
	PTB7,
	PTB8_NC,
	PTB9_NC,
	PTB10_NC,
	PTB11_NC,
	PTB12_NC,
	PTB13
};

enum {
	PTC0_NC=0,
	PTC1,
	PTC2,
	PTC3,
	PTC4,
	PTC5,
	PTC6,
	PTC7,
	PTC8,
	PTC9,
	PTC10_NC,
	PTC11_NC,
	PTC12_NC,
	PTC13_NC,
	PTC14,
	PTC15,
	PTC16,
	PTC17_NC
};

enum {
	PTD0=0,
	PTD1,
	PTD2,
	PTD3,
	PTD4,
	PTD5,
	PTD6_NC,
	PTD7_NC,
	PTD8_NC,
	PTD9_NC,
	PTD10_NC,
	PTD11_NC,
	PTD12_NC,
	PTD13_NC,
	PTD14_NC,
	PTD15,
	PTD16,
	PTD17_NC
};

enum {
	PTE0_NC=0,
	PTE1_NC,
	PTE2_NC,
	PTE3_NC,
	PTE4,
	PTE5,
	PTE6_NC,
	PTE7_NC,
	PTE8,
	PTE9,
	PTE10,
	PTE11
};

// output parameters
enum {
	LOW=0,
	HIGH,
};

enum {
	FALSE=0,
	TRUE
};

enum {
	STOP=0,
	LEFT,
	RIGHT
};

enum {
    NONE=0,
    GPIO,
    PWM
};

enum {
	MOTOR=0,
	LIGHTS
};

// error/success definitions
enum {
	SUCCESS=0,
	ERROR
};

// structure used for stepper control
struct StepperStruct {
	unsigned int Position;
	unsigned int Direction;
	unsigned int StepsToGo;
	unsigned int Mode;
};

// Simple pin config macro for the H-Bridge control pins
// Mode can be either NONE, GPIO or PWM
#define PinConfig(port, pin, mode) port->PCR[pin] = PORT_PCR_MUX(mode)

// This is the period of a PWM cycle (210Hz@12MHz FTM base clock)
#define MaxPwmPeriod 0xDF36

// DIP Switch [4:0]=[PTC[5:4],PTA[3:1]]
#define DIP1 PTD0
#define DIP2 PTD1
#define DIP3 PTD2
#define DIP4 PTD3
#define DIP5 PTC5
//#define DIP_Bits (1<<DIP5|1<<DIP4|1<<DIP3|1<<DIP2|1<<DIP1)

// E Inputs
#define E1 PTC3
#define E2 PTC2
#define E3 PTC1
#define E4 PTC16
#define E5 PTA0
#define E6 PTA1
#define E7 PTB1
#define E8 PTB0
#define Ex_Bits (1<<E1|1<<E2|1<<E3|1<<E4|1<<E5|1<<E6|1<<E7|1<<E8)

#define Eingang(x) (E_Input&(1<<(x-1)))
#define PosEdgeOnInput(x) (DigitalInputPosEdges&(1<<(x-1)))
#define NegEdgeOnInput(x) (DigitalInputNegEdges&(1<<(x-1)))
#define EdgeOnRawInput(x) (RawInputEdges&(1<<(x-1)))

#define POTI	PTA7
#define POTIHIGH (E_input_adc[8] >= 0x810)
#define POTILOW (E_input_adc[8] <= 0x7f0)

// Control outputs for H-Bridge
#define PORT_IN12 PTB
#define PORT_IN34 PTC

// H-Bridge 1
#define IN1 (PORTB->PCR[PTB2])
#define IN2 (PORTB->PCR[PTB3])
#define IN3 (PORTC->PCR[PTC14])
#define IN4 (PORTC->PCR[PTC15])

#define IN1_PIN	PTB2
#define IN2_PIN PTB3
#define IN3_PIN PTC14
#define IN4_PIN PTC15

// H-Bridge 2
#define IN5_PIN	PTA10
#define IN6_PIN PTA11
#define IN7_PIN PTA12
#define IN8_PIN PTA13

#define LED PTE9
#define LED_Bit (1<<LED)
#define LEDToggle	IP_PTE->PTOR = LED_Bit;
#define LEDOff		IP_PTE->PSOR = LED_Bit;
#define LEDOn 		IP_PTE->PCOR = LED_Bit;

#define FaultPin1 PTC9
#define FaultPin2 PTC8
#define FaultPin1_Bit	(1<<FaultPin1)
#define FaultPin2_Bit	(1<<FaultPin2)

#define EnableRTC 	IP_LPTMR0->CSR = LPTMR_CSR_TEN_MASK; 	// enable LPTMR0
#define DisableRTC	IP_LPTMR0->CSR = 0x00;					// disbale LPTMR0
#define RTCTimeout	(IP_LPTMR0->CSR & LPTMR_CSR_TCF_MASK)
#define ClearRTC	(IP_LPTMR0->CSR |= LPTMR_CSR_TCF_MASK);	// clear compare flag

#define PrepareTimeoutMS(x)	SetTimeout=x
#define DisableTimeoutMS	SetTimeout=0
#define Timeout (SetTimeout==0)
//#define TimeoutOccurred (SetTimeout==0)

// From iic.h
// DRV8847
#define HB_Address_ALL		0x60
#define HB_Address_HB1		0x65
#define HB_Address_HB2		0x6a
#define HB_SLAVE_ADDR_REG	0x00
#define HB_IC1_CON_REG		0x01
#define HB_IC2_CON_REG		0x02
#define HB_SLR_STATUS1_REG	0x03
#define HB_STATUS2_REG		0x04
#define HB_4PIN_MODE		0x00
#define HB_INDEP_MODE		0x03

// TCA6408
#define PT_Addr				0x20
#define PT_InputReg			0x00
#define PT_OutputReg		0x01
#define PT_PolarityReg		0x02
#define PT_ConfigReg		0x03

// PCF2127
#define RTC_Addr			0x51
#define RTC_SecReg			0x03

#endif /* FT_RPI_SA_CONTROLLER_FT_RPI_SA_CONTROLLER_H_ */

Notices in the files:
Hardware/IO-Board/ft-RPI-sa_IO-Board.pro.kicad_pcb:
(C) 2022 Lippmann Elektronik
